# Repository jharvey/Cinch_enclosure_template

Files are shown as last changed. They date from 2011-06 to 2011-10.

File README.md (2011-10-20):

### EMS controller

This is a Cinch ModeICE enclosure layout template. The intent is that this will function as a starting point containing the critical items of an engine management system, such that one can insert thier CPU of choice and much of the hardware layout ect has already been drafted.

It includes the enclosure with thermal bars, left and right spring brackets, and a couple of potentail connectors that includes lots of great layout details. Included are the OEM Cinch 60 pin harness connector, and a Molex 112 pin connector.

The 3D of the enclosure was provided by Modice and is not the offical copy, it is current at the time this was created, but it could get out of date. The 3D assembly models are were often created in solidworks, and then imported to KICAD via TTConv0.2.

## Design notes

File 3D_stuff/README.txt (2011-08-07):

For the full 3Dstuff dir, that includes Solidworks files, DXF files, and other such CAD, see this github copy

commit  c3bbe558f4f0b5641e87
tree    d143f92a7165eae8b8e6
parent  c4be0f84e3a4aa974f0e

For zipped copy of 3DSTUFF folder see this copy in git hub

commit  38f78dee2a54a77aab6d
tree    d58a619a9214489eaf4b
parent  c3bbe558f4f0b5641e87

3DSTUFF folder was removed for space purposes.

I have included two step files of the assembly, these contain the outside faces, and the larger one include a rough idea of what's inside the enclosure.

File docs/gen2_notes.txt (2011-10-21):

Notes for gen2

Different harness connector, one that goes straight to the PCB, and has power devices dumping heat out the back. Perhaps with 2 connectors such that analog stuff can appraoch the processor in a start config. 

install the SP720 and SP723 earlier on, such that they are included.

Modularize parts if it like th injectocts, such that sub boards can be bulk processed. For example, 4 low side drive, or the WO2 circuit.

change AN/DIGI protect parts to smaller SMT, such that they can be packed tighter together.

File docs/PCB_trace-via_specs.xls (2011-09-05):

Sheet: .5oz PCB_trace-via_specs
Key notes from the below (summary .5oz copper)
A min trace width of 10 mills, is good for 8/8 PCB houses and can handle .537 external amps and .268 internal amps
For 1 amp and .5 oz copper, use a trace width wider than 23.7 mil external, and 61.5 mills internal. Min via drill of 20 mil.
For 5 amp and .5 oz copper, use a trace width wider than 218 mil external, and 566 mills internal. Min via drill of 45 mil.
For 10 amp and .5 oz copper, use a trace width wider than 566 mil external, and 1470 mills internal. Min via drill of 123 mil.
Per online calculator found here http://circuitcalculator.com/wordpress/2006/01/31/pcb-trace-width-calculator
min via's from http://batchpcb.com/index.php/Faq via calcs from http://circuitcalculator.com/wordpress/2006/03/12/pcb-via-calculator/
10 mill wide trace (min recommended for an 8/8 PCB house) |  |  |  | 13 mil min drill diameter
current .537 A |  | current .268 A |  | 15 | mil finished hole dia
.5 oz/ft^2 |  | .5 oz/ft^2 |  | 1 | mil plating thickness
temp rise 10 c |  | temp rise 10 c |  | 60 | mil via length
ambient 25 c |  | ambient 25 c
1 inch long |  | 1 inch long |  | 4 | amps applied
 |  |  |  | 1.9e-06 | Ohm-cm plating resistivity
--- for and external trace--- |  | --- for an internal trace---
internal trace |  | internal trace |  | 0.000893 | Ohms
26.1 | mill | 10 | mill | 0.0357 | Volts dropped
0.0387 | ohm | 0.1010 | ohm | 0.0143 | Watts dissipated
0.0208 | V drop | 0.0270 | V drop | 2.26 | Amps estimated ampacity
0.0112 | Watts | 0.00724 | Watts
external trace |  | external trace
10 | mill | 3.85 | mill
0.1010 | ohm | 0.262 | ohm
0.0540 | V drop | 0.070 | V drop
0.0290 | Watts | 0.019 | Watts
Trace width |  |  | via calcs
current 1 A |  |  | 15 | mil finished hole dia
.5 oz/ft^2 |  |  | 1 | mil plating thickness
temp rise 10 c |  |  | 60 | mil via length
ambient 25 c |  |  | 13 | drill dia
1 inch long |  |  | 1 | amps applied
 |  |  | 1.9e-06 | Ohm-cm plating resistivity
internal trace
61.5 | mill |  | 0.000893 | Ohms
0.0164 | ohm |  | 0.0357 | Volts dropped
0.0164 | V drop |  | 0.0143 | Watts dissipated
0.0164 | Watts |  | 2.26 | Amps estimated ampacity
external trace
23.7 | mill
0.0427 | ohm
0.0427 | V drop
0.0427 | Watts
Trace width |  |  | via calcs
current 5 A |  |  | 47 | mil finished hole dia
.5 oz/ft^2 |  |  | 1 | mil plating thickness
temp rise 10 c |  |  | 60 | mil via length
ambient 25 c |  |  | 45 | drill dia
1 inch long |  |  | 1 | amps applied
 |  |  | 1.9e-06 | Ohm-cm plating resistivity
internal trace
566 | mill |  | 0.000298 | Ohms
0.0018 | ohm |  | 0.00149 | Volts dropped
0.0089 | V drop |  | 0.00744 | Watts dissipated
0.0445 | Watts |  | 5.02 | Amps estimated ampacity
external trace
218 | mill
0.0046 | ohm
0.0232 | V drop
0.1160 | Watts
Trace width |  |  | via calcs
current 10 A |  |  | 125 | mil finished hole dia
.5 oz/ft^2 |  |  | 1 | mil plating thickness
temp rise 10 c |  |  | 60 | mil via length
ambient 25 c |  |  | 123 | drill dia
1 inch long |  |  | 10 | amps applied
 |  |  | 1.9e-06 | Ohm-cm plating resistivity
internal trace
14700 | mill |  | 0.000113 | Ohms
0.0007 | ohm |  | 0.00113 | Volts dropped
0.0069 | V drop |  | 0.0113 | Watts dissipated
0.0685 | Watts |  | 10.1 | Amps estimated ampacity
external trace
566 | mill
0.0018 | ohm
0.0178 | V drop
0.1780 | Watts

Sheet: 1oz PCB_trace-via_specs
Key notes from the below (summary 1oz copper)
A min trace width of 10 mills, is good for 8/8 PCB houses and can handle .886 external amps and .444 internal amps
For 1 amp and 1 oz copper, use a trace width wider than 11.8 mil external, and 30.8 mills internal. Min via drill of 20 mil.
For 5 amp and 1 oz copper, use a trace width wider than 109 mil external, and 283 mills internal. Min via drill of 45 mil.
For 10 amp and 1 oz copper, use a trace width wider than 283 mil external, and 737 mills internal. Min via drill of 123 mil.
Per online calculator found here http://circuitcalculator.com/wordpress/2006/01/31/pcb-trace-width-calculator
min via's from http://batchpcb.com/index.php/Faq via calcs from http://circuitcalculator.com/wordpress/2006/03/12/pcb-via-calculator/
9 mill wide trace (KICAD help file class 4 IPC class?) |  |  |  | 13 mil min drill diameter
current .8201 A |  | current .4101 A |  | 15 | mil finished hole dia
1 oz/ft^2 |  | 1 oz/ft^2 |  | 1 | mil plating thickness
temp rise 10 c |  | temp rise 10 c |  | 60 | mil via length
ambient 25 c |  | ambient 25 c
1 inch long |  | 1 inch long |  | 4 | amps applied
 |  |  |  | 1.9e-06 | Ohm-cm plating resistivity
--- for and external trace--- |  | --- for an internal trace---
internal trace |  | internal trace |  | 0.000893 | Ohms
23.4 | mill | 9 | mill | 0.0357 | Volts dropped
0.0216 | ohm | 0.0561 | ohm | 0.0143 | Watts dissipated
0.0177 | V drop | 0.0230 | V drop | 2.26 | Amps estimated ampacity
0.0145 | Watts | 0.0094 | Watts
external trace |  | external trace
9 | mill | 3.46 | mill
0.0561 | ohm | 0.146 | ohm
0.0460 | V drop | 0.060 | V drop
0.0377 | Watts | 0.025 | Watts
10 mill wide trace (min recommended for an 8/8 PCB house) |  |  |  | 20 mil min drill diameter
current .886 A |  | current .444 A |  | 22 | mil finished hole dia
1 oz/ft^2 |  | 1 oz/ft^2 |  | 1 | mil plating thickness
temp rise 10 c |  | temp rise 10 c |  | 60 | mil via length
ambient 25 c |  | ambient 25 c
1 inch long |  | 1 inch long |  | 2.94 | amps applied
 |  |  |  | 1.9e-06 | Ohm-cm plating resistivity
--- for and external trace--- |  | --- for an internal trace---
internal trace |  | internal trace |  | 0.000621 | Ohms
26 | mill | 10 | mill | 0.00183 | Volts dropped
0.0194 | ohm | 0.0503 | ohm | 0.00537 | Watts dissipated
0.0172 | V drop | 0.0223 | V drop | 2.94 | Amps estimated ampacity
0.0152 | Watts | 0.0099 | Watts
external trace |  | external trace
10 | mill | 3.86 | mill
0.0504 | ohm | 0.131 | ohm
0.0447 | V drop | 0.058 | V drop
0.0396 | Watts | 0.026 | Watts
Trace width |  |  | via calcs
current 1 A |  |  | 15 | mil finished hole dia
1 oz/ft^2 |  |  | 1 | mil plating thickness
temp rise 10 c |  |  | 60 | mil via length
ambient 25 c |  |  | 13 | drill dia
1 inch long |  |  | 1 | amps applied
 |  |  | 1.9e-06 | Ohm-cm plating resistivity
internal trace
30.8 | mill |  | 0.000893 | Ohms
0.0164 | ohm |  | 0.0357 | Volts dropped
0.0164 | V drop |  | 0.0143 | Watts dissipated
0.0164 | Watts |  | 2.26 | Amps estimated ampacity
external trace
11.8 | mill
0.0427 | ohm
0.0427 | V drop
0.0427 | Watts
Trace width |  |  | via calcs
current 5 A |  |  | 47 | mil finished hole dia
1 oz/ft^2 |  |  | 1 | mil plating thickness
temp rise 10 c |  |  | 60 | mil via length
ambient 25 c |  |  | 45 | drill dia
1 inch long |  |  | 1 | amps applied
 |  |  | 1.9e-06 | Ohm-cm plating resistivity
internal trace
283 | mill |  | 0.000298 | Ohms
0.0018 | ohm |  | 0.00149 | Volts dropped
0.0089 | V drop |  | 0.00744 | Watts dissipated
0.0445 | Watts |  | 5.02 | Amps estimated ampacity
external trace
109 | mill
0.0046 | ohm
0.0232 | V drop
0.1160 | Watts
Trace width |  |  | via calcs
current 10 A |  |  | 125 | mil finished hole dia
1 oz/ft^2 |  |  | 1 | mil plating thickness
temp rise 10 c |  |  | 60 | mil via length
ambient 25 c |  |  | 123 | drill dia
1 inch long |  |  | 10 | amps applied
 |  |  | 1.9e-06 | Ohm-cm plating resistivity
internal trace
737 | mill |  | 0.000113 | Ohms
0.0007 | ohm |  | 0.00113 | Volts dropped
0.0069 | V drop |  | 0.0113 | Watts dissipated
0.0685 | Watts |  | 10.1 | Amps estimated ampacity
external trace
283 | mill
0.0018 | ohm
0.0178 | V drop
0.1780 | Watts

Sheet: 2oz PCB_trace-via_specs
Key notes from the below (summary 2oz copper)
A min trace width of 10 mills, is good for 8/8 PCB houses and can handle 1.465 external amps and .734 internal amps
For 1 amp and 2 oz copper, use a trace width wider than 5.91 mil external, and 15.4 mills internal. Min via drill of 20 mil.
For 5 amp and 2 oz copper, use a trace width wider than 54.4 mil external, and 142 mills internal. Min via drill of 45 mil.
For 10 amp and 2 oz copper, use a trace width wider than 142 mil external, and 368 mills internal. Min via drill of 123 mil.
Per online calculator found here http://circuitcalculator.com/wordpress/2006/01/31/pcb-trace-width-calculator
min via's from http://batchpcb.com/index.php/Faq via calcs from http://circuitcalculator.com/wordpress/2006/03/12/pcb-via-calculator/
10 mill wide trace (min recommended for an 8/8 PCB house) |  |  |  | 20 mil min drill diameter
current 1.465 A |  | current .734 A |  | 22 | mil finished hole dia
2 oz/ft^2 |  | 2 oz/ft^2 |  | 1 | mil plating thickness
temp rise 10 c |  | temp rise 10 c |  | 60 | mil via length
ambient 25 c |  | ambient 25 c
1 inch long |  | 1 inch long |  | 2.94 | amps applied
 |  |  |  | 1.9e-06 | Ohm-cm plating resistivity
--- for and external trace--- |  | --- for an internal trace---
internal trace |  | internal trace |  | 0.000621 | Ohms
26 | mill | 10 | mill | 0.00183 | Volts dropped
0.0097 | ohm | 0.0251 | ohm | 0.00537 | Watts dissipated
0.0421 | V drop | 0.0184 | V drop | 2.94 | Amps estimated ampacity
0.0208 | Watts | 0.0135 | Watts
external trace |  | external trace
10 | mill | 3.86 | mill
0.0252 | ohm | 0.065 | ohm
0.0369 | V drop | 0.048 | V drop
0.0541 | Watts | 0.035 | Watts
Trace width |  |  | via calcs
current 1 A |  |  | 15 | mil finished hole dia
2 oz/ft^2 |  |  | 1 | mil plating thickness
temp rise 10 c |  |  | 60 | mil via length
ambient 25 c |  |  | 13 | drill dia
1 inch long |  |  | 1 | amps applied
 |  |  | 1.9e-06 | Ohm-cm plating resistivity
internal trace
15.4 | mill |  | 0.000893 | Ohms
0.0164 | ohm |  | 0.0357 | Volts dropped
0.0164 | V drop |  | 0.0143 | Watts dissipated
0.0164 | Watts |  | 2.26 | Amps estimated ampacity
external trace
5.91 | mill
0.0427 | ohm
0.0427 | V drop
0.0427 | Watts
Trace width |  |  | via calcs
current 5 A |  |  | 47 | mil finished hole dia
2 oz/ft^2 |  |  | 1 | mil plating thickness
temp rise 10 c |  |  | 60 | mil via length
ambient 25 c |  |  | 45 | drill dia
1 inch long |  |  | 1 | amps applied
 |  |  | 1.9e-06 | Ohm-cm plating resistivity
internal trace
142 | mill |  | 0.000298 | Ohms
0.0018 | ohm |  | 0.00149 | Volts dropped
0.0089 | V drop |  | 0.00744 | Watts dissipated
0.0445 | Watts |  | 5.02 | Amps estimated ampacity
external trace
54.4 | mill
0.0046 | ohm
0.0232 | V drop
0.1160 | Watts
Trace width |  |  | via calcs
current 10 A |  |  | 125 | mil finished hole dia
2 oz/ft^2 |  |  | 1 | mil plating thickness
temp rise 10 c |  |  | 60 | mil via length
ambient 25 c |  |  | 123 | drill dia
1 inch long |  |  | 10 | amps applied
 |  |  | 1.9e-06 | Ohm-cm plating resistivity
internal trace
368 | mill |  | 0.000113 | Ohms
0.0007 | ohm |  | 0.00113 | Volts dropped
0.0069 | V drop |  | 0.0113 | Watts dissipated
0.0685 | Watts |  | 10.1 | Amps estimated ampacity
external trace
142 | mill
0.0018 | ohm
0.0178 | V drop
0.1780 | Watts

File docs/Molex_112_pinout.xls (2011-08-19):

Connector | pin# |  | pin size | Signal | Alt signal | notes
1 - Center | 1 | A | small | Ign 1
1 - Center | 1 | B | small | optout 1
1 - Center | 1 | C | small | 5V sensor supply
1 - Center | 1 | D | small | Crank+
1 - Center | 1 | E | small | O2 VM 1
1 - Center | 1 | F | small | CAN1 L
1 - Center | 1 | G | small | GND sense
1 - Center | 1 | H | small | optout 5
1 - Center | 1 | J | small | 5V general supply |  | do we need this?
1 - Center | 1 | K | small | Stepper 1-1
1 - Center | 1 | L | large | GND 1-1
1 - Center | 1 | M | large | Inj 1
1 - Center | 2 | A | small | Ign 2
1 - Center | 2 | B | small | optout 2
1 - Center | 2 | C | small | MAP
1 - Center | 2 | D | small | Crank-
1 - Center | 2 | E | small | O2 UM1
1 - Center | 2 | F | small | CAN1 H
1 - Center | 2 | G | small | Analog in 2
1 - Center | 2 | H | small | optout 6
1 - Center | 2 | J | small | Knock 1 +
1 - Center | 2 | K | small | Stepper 1-2
1 - Center | 2 | L | large | GND 1-2
1 - Center | 2 | M | large | Inj 2
1 - Center | 3 | A | small | Ign 3
1 - Center | 3 | B | small | optout 3
1 - Center | 3 | C | small | TPS
1 - Center | 3 | D | small | Cam+
1 - Center | 3 | E | small | O2 IP 1
1 - Center | 3 | F | small | 232 RX
1 - Center | 3 | G | small | Analog in 1
1 - Center | 3 | H | small | Analog in 4
1 - Center | 3 | J | small | Knock 1 -
1 - Center | 3 | K | small | Stepper 1-3
1 - Center | 3 | L | large | Fuel pump
1 - Center | 3 | M | large | Inj 3
1 - Center | 4 | A | small | Ign 4
1 - Center | 4 | B | small | opt out 4
1 - Center | 4 | C | small | Coolant Temp
1 - Center | 4 | D | small | Cam-
1 - Center | 4 | E | small | O2 1 - IA 1
1 - Center | 4 | F | small | 232 TX
1 - Center | 4 | G | small | Air Temp
1 - Center | 4 | H | small | O2 Heater 1
1 - Center | 4 | J | small | Analog in 3
1 - Center | 4 | K | small | Stepper 1-4
1 - Center | 4 | L | large | 12V 1
1 - Center | 4 | M | large | Inj 4
2 - Left | 1 | A | small | Ign 5
2 - Left | 1 | B | small | Analog in 5
2 - Left | 1 | C | small | O2 VM2
2 - Left | 1 | D | small | wheel 1 +
2 - Left | 1 | E | small | wheel 1 -
2 - Left | 1 | F | small | Stepper 2 - 1
2 - Left | 1 | G | large | GND 2-1
2 - Left | 1 | H | large | Inj 5
2 - Left | 2 | A | small | Ign 6
2 - Left | 2 | B | small | Analog in 6
2 - Left | 2 | C | small | O2 UM2
2 - Left | 2 | D | small | wheel 2 +
2 - Left | 2 | E | small | wheel 2 -
2 - Left | 2 | F | small | Stepper 2 - 2
2 - Left | 2 | G | large | GND 2-1
2 - Left | 2 | H | large | Inj 6
2 - Left | 3 | A | small | Ign 7
2 - Left | 3 | B | small | Analog in 7
2 - Left | 3 | C | small | O2 IP2
2 - Left | 3 | D | small | wheel 3 +
2 - Left | 3 | E | small | wheel 3 -
2 - Left | 3 | F | small | Stepper 2 - 3
2 - Left | 3 | G | large | GND2-2
2 - Left | 3 | H | large | Inj 7
2 - Left | 4 | A | small | Ign 8
2 - Left | 4 | B | small | O2 Heater2
2 - Left | 4 | C | small | O2 2 - IA
2 - Left | 4 | D | small | wheel 4 +
2 - Left | 4 | E | small | wheel 4 -
2 - Left | 4 | F | small | Stepper 2- 4
2 - Left | 4 | G | large | 12V 2
2 - Left | 4 | H | large | Inj 8
3 - Right | 1 | A | small | Ign 9
3 - Right | 1 | B | small | optout 7 | inj 13
3 - Right | 1 | C | small | optout 11 | inj 17
3 - Right | 1 | D | small | optout 15 | inj 21
3 - Right | 1 | E | small | Analog in 8
3 - Right | 1 | F | small | analog in 9
3 - Right | 1 | G | large | GND 3-1
3 - Right | 1 | H | large | Inj 9
3 - Right | 2 | A | small | Ign 10
3 - Right | 2 | B | small | optout 8 | inj 14
3 - Right | 2 | C | small | optout 12 | inj 18
3 - Right | 2 | D | small | optout 16 | inj 22
3 - Right | 2 | E | small | analog in 10
3 - Right | 2 | F | small | analog in 11
3 - Right | 2 | G | large | GND 3-2
3 - Right | 2 | H | large | Inj 10
3 - Right | 3 | A | small | Ign 11
3 - Right | 3 | B | small | optout 9 | inj 15
3 - Right | 3 | C | small | optout 13 | inj 19
3 - Right | 3 | D | small | optout 17 | inj 23
3 - Right | 3 | E | small | 232 TX2 |  | do we need this?
3 - Right | 3 | F | small | CAN2 L |  | do we need this?
3 - Right | 3 | G | large | GND3-3
3 - Right | 3 | H | large | Inj 11
3 - Right | 4 | A | small | Ign 12
3 - Right | 4 | B | small | optout 10 | inj 16
3 - Right | 4 | C | small | optout 14 | inj 20
3 - Right | 4 | D | small | optout 18 | inj 24
3 - Right | 4 | E | small | 232 RX2 |  | do we need this?
3 - Right | 4 | F | small | CAN2 H |  | do we need this?
3 - Right | 4 | G | large | GND3-4
3 - Right | 4 | H | large | Inj 12

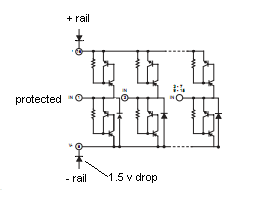
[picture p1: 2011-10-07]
pictures/ESD_theory.PNG

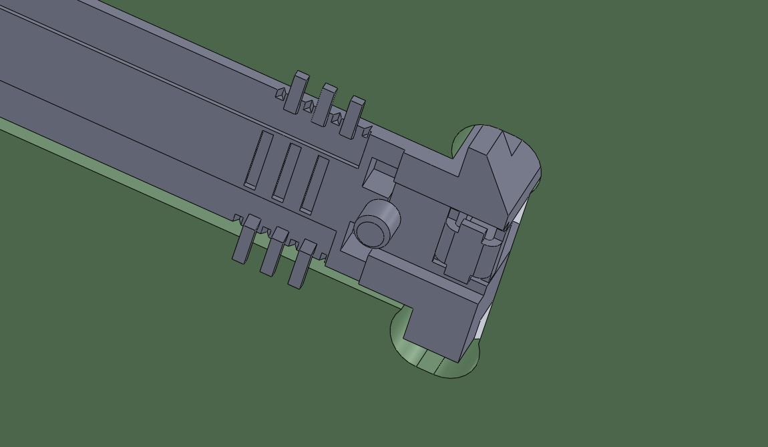
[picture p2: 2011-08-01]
pictures/som_bottom_view.jpg

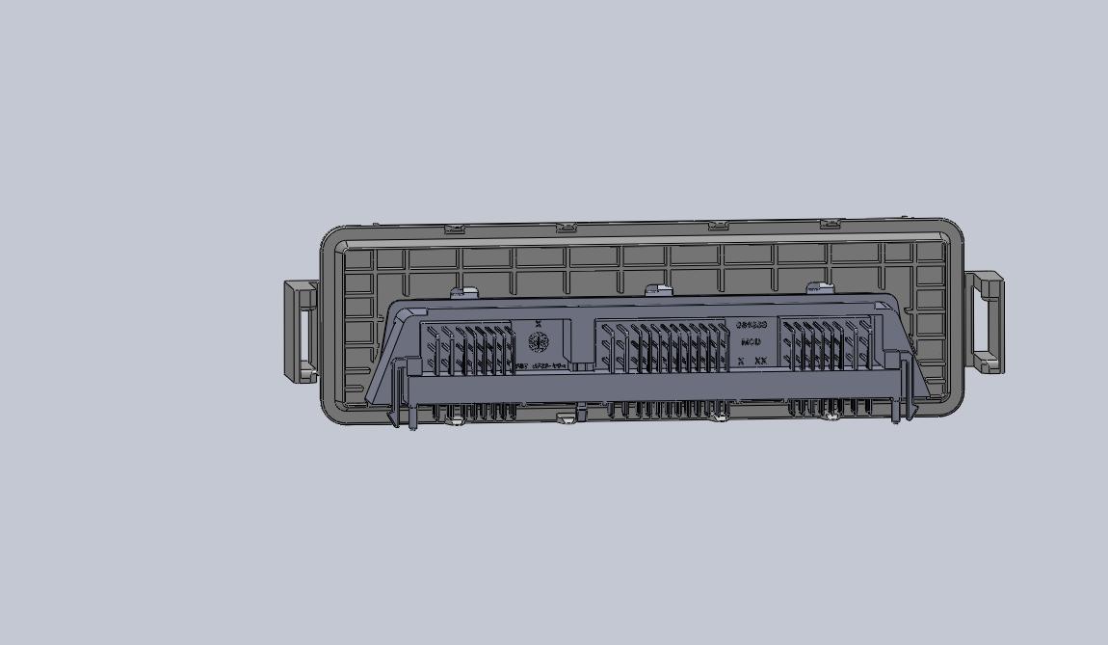
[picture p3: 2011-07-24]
pictures/modeice_case_iso3.jpg

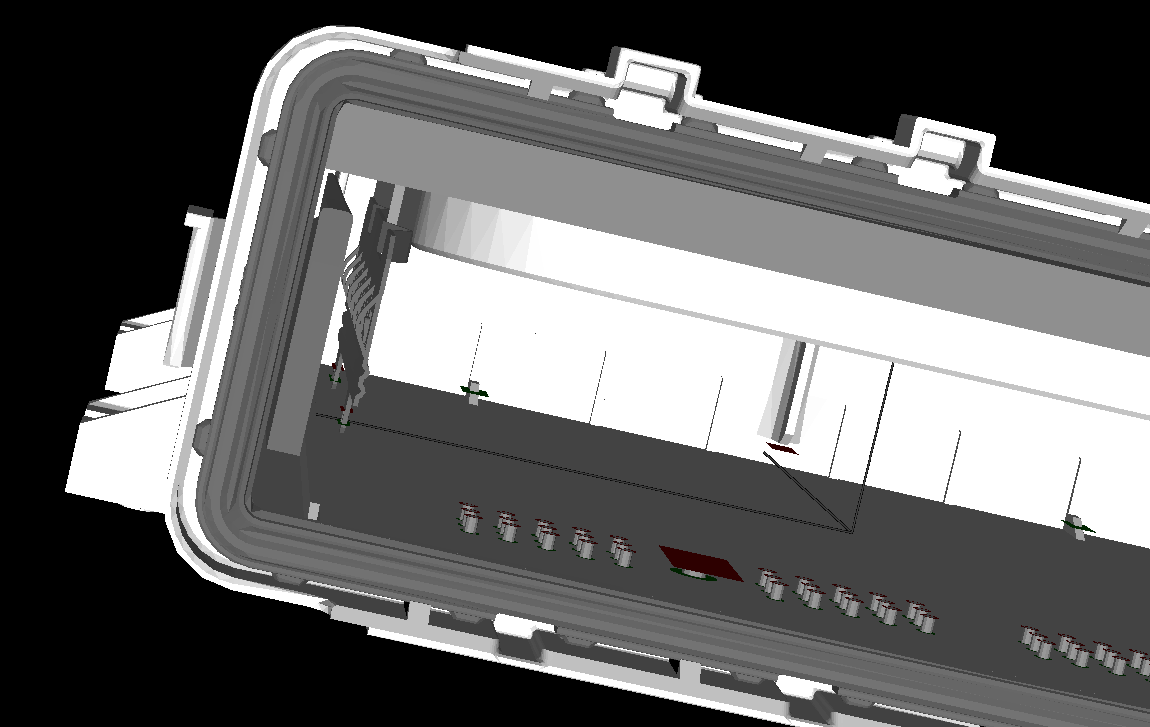
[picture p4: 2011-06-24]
pictures/cinch_spring_clips1.png

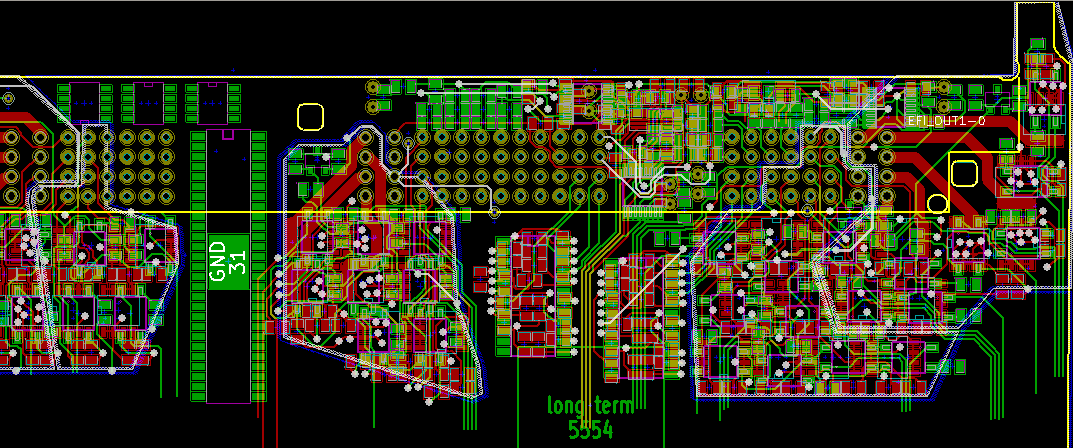
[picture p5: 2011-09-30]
pictures/layout_top_view_09-26-11.PNG

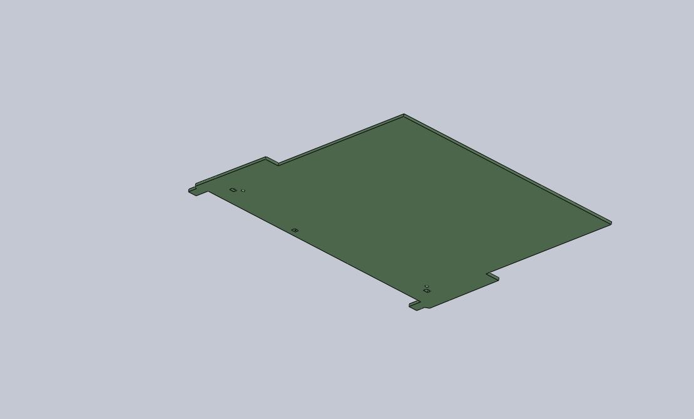
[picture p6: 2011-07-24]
pictures/pcb_outline.jpg

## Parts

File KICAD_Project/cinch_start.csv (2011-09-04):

ref | value | footprint | Field1 | Field2 | Field3 | Field4 | Field5 | Field6 | Field7 | Field8
C401 | 100nf | SM0805-C1 | avx | 08051C104KAT2A | newark | 96M1354 |  |  | 100V | 10% | ceramic | other | more | stuff
C402 | 100nf | SM0805-C1 | avx | 08051C104KAT2A | newark | 96M1354 |  |  | 100V | 10% | ceramic | other | more | stuff
C403 | 100nf | SM0805-C1 | avx | 08051C104KAT2A | newark | 96M1354 |  |  | 100V | 10% | ceramic | other | more | stuff
C404 | 100nf | SM0805-C1 | avx | 08051C104KAT2A | newark | 96M1354 |  |  | 100V | 10% | ceramic | other | more | stuff
C405 | 100nf | SM0805-C1 | avx | 08051C104KAT2A | newark | 96M1354 |  |  | 100V | 10% | ceramic | other | more | stuff
C406 | 100nf | SM0805-C1 | avx | 08051C104KAT2A | newark | 96M1354 |  |  | 100V | 10% | ceramic | other | more | stuff
C407 | 100nf | SM0805-C1 | avx | 08051C104KAT2A | newark | 96M1354 |  |  | 100V | 10% | ceramic | other | more | stuff
C408 | 100nf | SM0805-C1 | avx | 08051C104KAT2A | newark | 96M1354 |  |  | 100V | 10% | ceramic | other | more | stuff
C409 | 100nf | SM0805-C1 | avx | 08051C104KAT2A | newark | 96M1354 |  |  | 100V | 10% | ceramic | other | more | stuff
C410 | 100nf | SM0805-C1 | avx | 08051C104KAT2A | newark | 96M1354 |  |  | 100V | 10% | ceramic | other | more | stuff
C411 | 100nf | SM0805-C1 | avx | 08051C104KAT2A | newark | 96M1354 |  |  | 100V | 10% | ceramic | other | more | stuff
C412 | 100nf | SM0805-C1 | avx | 08051C104KAT2A | newark | 96M1354 |  |  | 100V | 10% | ceramic | other | more | stuff
C413 | 100nf | SM0805-C1 | avx | 08051C104KAT2A | newark | 96M1354 |  |  | 100V | 10% | ceramic | other | more | stuff
C414 | 100nf | SM0805-C1 | avx | 08051C104KAT2A | newark | 96M1354 |  |  | 100V | 10% | ceramic | other | more | stuff
C415 | 100nf | SM0805-C1 | avx | 08051C104KAT2A | newark | 96M1354 |  |  | 100V | 10% | ceramic | other | more | stuff
C416 | 100nf | SM0805-C1 | avx | 08051C104KAT2A | newark | 96M1354 |  |  | 100V | 10% | ceramic | other | more | stuff
C417 | 100nf | SM0805-C1 | avx | 08051C104KAT2A | newark | 96M1354 |  |  | 100V | 10% | ceramic | other | more | stuff
C418 | 100nf | SM0805-C1 | avx | 08051C104KAT2A | newark | 96M1354 |  |  | 100V | 10% | ceramic | other | more | stuff
C419 | 100nf | SM0805-C1 | avx | 08051C104KAT2A | newark | 96M1354 |  |  | 100V | 10% | ceramic | other | more | stuff
C420 | 100nf | SM0805-C1 | avx | 08051C104KAT2A | newark | 96M1354 |  |  | 100V | 10% | ceramic | other | more | stuff
C421 | 100nf | SM0805-C1 | avx | 08051C104KAT2A | newark | 96M1354 |  |  | 100V | 10% | ceramic | other | more | stuff
C422 | 100nf | SM0805-C1 | avx | 08051C104KAT2A | newark | 96M1354 |  |  | 100V | 10% | ceramic | other | more | stuff
C423 | 100nf | SM0805-C1 | avx | 08051C104KAT2A | newark | 96M1354 |  |  | 100V | 10% | ceramic | other | more | stuff
C424 | 100nf | SM0805-C1 | avx | 08051C104KAT2A | newark | 96M1354 |  |  | 100V | 10% | ceramic | other | more | stuff
C425 | 100nf | SM0805-C1 | avx | 08051C104KAT2A | newark | 96M1354 |  |  | 100V | 10% | ceramic | other | more | stuff
C426 | 100nf | SM0805-C1 | avx | 08051C104KAT2A | newark | 96M1354 |  |  | 100V | 10% | ceramic | other | more | stuff
C427 | 100nf | SM0805-C1 | avx | 08051C104KAT2A | newark | 96M1354 |  |  | 100V | 10% | ceramic | other | more | stuff
C428 | 100nf | SM0805-C1 | avx | 08051C104KAT2A | newark | 96M1354 |  |  | 100V | 10% | ceramic | other | more | stuff
C501 | 1uF | SM0805 | avx | 08051C103JAT2A | newark | 96M1352
C502 | 1uF | SM0805 | avx | 08051C103JAT2A | newark | 96M1352
C503 | 1uF | SM0805 | avx | 08051C103JAT2A | newark | 96M1352
C504 | 1uF | SM0805 | avx | 08051C103JAT2A | newark | 96M1352
C505 | 1uF | SM0805 | avx | 08051C103JAT2A | newark | 96M1352
C506 | 1uF | SM0805 | avx | 08051C103JAT2A | newark | 96M1352
C507 | 1uF | SM0805 | avx | 08051C103JAT2A | newark | 96M1352
C508 | 1uF | SM0805 | avx | 08051C103JAT2A | newark | 96M1352
C509 | 1uF | SM0805 | avx | 08051C103JAT2A | newark | 96M1352
C510 | 1uF | SM0805 | avx | 08051C103JAT2A | newark | 96M1352
C511 | 1uF | SM0805 | avx | 08051C103JAT2A | newark | 96M1352
C512 | 1uF | SM0805 | avx | 08051C103JAT2A | newark | 96M1352
C513 | 1uF | SM0805 | avx | 08051C103JAT2A | newark | 96M1352
C514 | 1uF | SM0805 | avx | 08051C103JAT2A | newark | 96M1352
C515 | 1uF | SM0805 | avx | 08051C103JAT2A | newark | 96M1352
C516 | 1uF | SM0805 | avx | 08051C103JAT2A | newark | 96M1352
C517 | 1uF | SM0805 | avx | 08051C103JAT2A | newark | 96M1352
C518 | 1uF | SM0805 | avx | 08051C103JAT2A | newark | 96M1352
C601 | 0.1uF | SM0805-C1 | avx | 08051C104KAT2A | newark | 96M1354 |  |  | 100V | 10% | ceramic | other | more | stuff
C602 | 0.1uF | SM0805-C1 | avx | 08051C104KAT2A | newark | 96M1354 |  |  | 100V | 10% | ceramic | other | more | stuff
C603 | 10uF | SM0805-C1 | AVX | 08053C104KAT2A | newark | 96M1381 |  |  | 25V | 10% | multi layer ceramic | other | more | stuff
C604 | 10uF | SM0805-C1 | AVX | 08053C104KAT2A | newark | 96M1381 |  |  | 25V | 10% | multi layer ceramic | other | more | stuff
C605 | 1nF | SM0805-C1 | avx | 08055F102K4Z2A | newark | 26M5154 | - | - | - | - | 10 | V | 10 | % | multilayer ceramic | other | more | stuff
C606 | 1nF | SM0805-C1 | avx | 08055F102K4Z2A | newark | 26M5154 | - | - | - | - | 50 | V | 10 | % | ceramic | other | more | stuff
C607 | 1nF | SM0805-C1 | avx | 08055F102K4Z2A | newark | 26M5154 | - | - | - | - | 10 | V | 10 | % | multilayer ceramic | other | more | stuff
C608 | 1nF | SM0805-C1 | avx | 08055F102K4Z2A | newark | 26M5154 | - | - | - | - | 50 | V | 10 | % | ceramic | other | more | stuff
C609 | 0.1uF | SM0805-C1 | avx | 08051C104KAT2A | newark | 96M1354 |  |  | 100V | 10% | ceramic | other | more | stuff
C610 | 0.1uF | SM0805-C1 | avx | 08051C104KAT2A | newark | 96M1354 |  |  | 100V | 10% | ceramic | other | more | stuff
C611 | 10uF | SM0805-C1 | AVX | 08053C104KAT2A | newark | 96M1381 |  |  | 25V | 10% | multi layer ceramic | other | more | stuff
C612 | 10uF | SM0805-C1 | AVX | 08053C104KAT2A | newark | 96M1381 |  |  | 25V | 10% | multi layer ceramic | other | more | stuff
C613 | 1nF | SM0805-C1 | avx | 08055F102K4Z2A | newark | 26M5154 | - | - | - | - | 10 | V | 10 | % | multilayer ceramic | other | more | stuff
C614 | 1nF | SM0805-C1 | avx | 08055F102K4Z2A | newark | 26M5154 | - | - | - | - | 50 | V | 10 | % | ceramic | other | more | stuff
C615 | 1nF | SM0805-C1 | avx | 08055F102K4Z2A | newark | 26M5154 | - | - | - | - | 10 | V | 10 | % | multilayer ceramic | other | more | stuff
C616 | 1nF | SM0805-C1 | avx | 08055F102K4Z2A | newark | 26M5154 | - | - | - | - | 50 | V | 10 | % | ceramic | other | more | stuff
C701 | 10uF | SM0805-C1 | AVX | 08053C104KAT2A | newark | 96M1381 |  |  | 25V | 10% | multi layer ceramic | other | more | stuff
C702 | 10uF | SM0805-C1 | AVX | 08053C104KAT2A | newark | 96M1381 |  |  | 25V | 10% | multi layer ceramic | other | more | stuff
C703 | 0.1uF | SM0805-C1 | avx | 08051C104KAT2A | newark | 96M1354 |  |  | 100V | 10% | ceramic | other | more | stuff
C704 | 0.1uF | SM0805-C1 | avx | 08051C104KAT2A | newark | 96M1354 |  |  | 100V | 10% | ceramic | other | more | stuff
C705 | 100nF | SM0805-C1 | avx | 08051C104KAT2A | newark | 96M1354 |  |  | 100V | 10% | ceramic | other | more | stuff
C706 | 10uF | SM0805-C1 | AVX | 08053C104KAT2A | newark | 96M1381 |  |  | 25V | 10% | multi layer ceramic | other | more | stuff
C707 | 0.1uF | SM0805-C1 | avx | 08051C104KAT2A | newark | 96M1354 |  |  | 100V | 10% | ceramic | other | more | stuff
C708 | 100uF | SM0805-C1 | avx | 08051C104KAT2A | newark | 96M1354 |  |  | 100V | 10% | ceramic | other | more | stuff
C709 | 100nF | SM0805-C1 | avx | 08051C104KAT2A | newark | 96M1354 |  |  | 100V | 10% | ceramic | other | more | stuff
C710 | 22uF | SM2512 | AVX | TAJC226M016RNJ | digikey | 478-3901-1-ND | 16v | 20% | tantalum | other | more | stuff
C711 | 22uF | SM2512 | AVX | TAJC226M016RNJ | digikey | 478-3901-1-ND | 16v | 20% | tantalum | other | more | stuff
C712 | 0.1uF | SM0805-C1 | avx | 08051C104KAT2A | newark | 96M1354 |  |  | 100V | 10% | ceramic | other | more | stuff
C713 | 0.1uF | SM0805-C1 | avx | 08051C104KAT2A | newark | 96M1354 |  |  | 100V | 10% | ceramic | other | more | stuff
C714 | 100uF | SM0805-C1 | avx | 08051C104KAT2A | newark | 96M1354 |  |  | 100V | 10% | ceramic | other | more | stuff
C715 | 100nF | SM0805-C1 | avx | 08051C104KAT2A | newark | 96M1354 |  |  | 100V | 10% | ceramic | other | more | stuff
C716 | 22uF | SM2512 | AVX | TAJC226M016RNJ | digikey | 478-3901-1-ND | 16v | 20% | tantalum | other | more | stuff
C717 | 0.1uF | SM0805-C1 | avx | 08051C104KAT2A | newark | 96M1354 |  |  | 100V | 10% | ceramic | other | more | stuff
C718 | 2200uF | C1V8 | United Chemi-Con | EKZE6R3ELL222MJ25S | digikey | 565-1634-ND | 6.3v | 20% | aluminum | other | more | stuff
C719 | 5.6nF | SM0805-C1 | ill cap | 226CKH050M | newark | 69K7919 | - | - | - | - | 50 | V | 20 | % | alum electro | other | more | stuff
C720 | 27pF | SM0805-C1 | avx | 08051A221JAT2A | newark | 96K4770 | - | - | - | - | 100 | V | 5 | % | ceramic | other | more | stuff
C721 | 330uF | SM0805-C1 | kemet | T495X337K010ATE035 | newark | 69K7939 | - | - | - | - | 25 | V | 20 | % | alum electro | other | more | stuff
C722 | 10uF | SM0805-C1 | AVX | 08053C104KAT2A | newark | 96M1381 |  |  | 25V | 10% | multi layer ceramic | other | more | stuff
C723 | 10nF | SM0805-C1 | ill cap | 106CKE200M | newark | 69K7896 |  |  | 200V | 10% | alum elec | other | more | stuff
C801 | 470uF | SM0805-C1 | ill cap | 106CKE200M | newark | 69K7896 | - | - | - | - | 200 | V | 20 | % | alum electro | other | more | stuff
C802 | 10uF | SM0805-C1 | AVX | 08053C104KAT2A | newark | 96M1381 |  |  | 25V | 10% | multi layer ceramic | other | more | stuff
C803 | 100nF | SM0805-C1 | avx | 08051C104KAT2A | newark | 96M1354 |  |  | 100V | 10% | ceramic | other | more | stuff
C804 | 470uF | SM0805-C1 | ill cap | 106CKE200M | newark | 69K7896 | - | - | - | - | 200 | V | 20 | % | alum electro | other | more | stuff
C805 | 100nF | SM0805-C1 | ill cap | 106CKE200M | newark | 69K7896 | - | - | - | - | 200 | V | 20 | % | alum electro | other | more | stuff
C901 | 22nF | SM0805-C1 | murata | GRM216R71H223KA01D | newark | 38K1698 | - | - | 50 | V | 10 | % | Ceramic | other | more | stuff
C902 | 10uF | SM0805-C1 | AVX | 08053C104KAT2A | newark | 96M1381 |  |  | 25V | 10% | multi layer ceramic | other | more | stuff
C903 | 100nF | SM0805-C1 | avx | 08051C104KAT2A | newark | 96M1354 |  |  | 100V | 10% | ceramic | other | more | stuff
C904 | 22nF | SM0805-C1 | murata | GRM216R71H223KA01D | newark | 38K1698 | - | - | 50 | V | 10 | % | Ceramic | other | more | stuff
C905 | 22nF | SM0805-C1 | murata | GRM216R71H223KA01D | newark | 38K1698 | - | - | 50 | V | 10 | % | Ceramic | other | more | stuff
C906 | 100nF | SM0805-C1 | avx | 08051C104KAT2A | newark | 96M1354 |  |  | 100V | 10% | ceramic | other | more | stuff
C907 | 100uF | SM0805-C1 | avx | 08051C104KAT2A | newark | 96M1354 |  |  | 100V | 10% | ceramic | other | more | stuff
C908 | 22nF | SM0805-C1 | murata | GRM216R71H223KA01D | newark | 38K1698 | - | - | 50 | V | 10 | % | Ceramic | other | more | stuff
C909 | 22nF | SM0805-C1 | murata | GRM216R71H223KA01D | newark | 38K1698 | - | - | 50 | V | 10 | % | Ceramic | other | more | stuff
C1001 | 10nF | SM0805-C1 | ill cap | 106CKE200M | newark | 69K7896 |  |  | 200V | 10% | alum elec | other | more | stuff
C1002 | 10nF | SM0805-C1 | ill cap | 106CKE200M | newark | 69K7896 |  |  | 200V | 10% | alum elec | other | more | stuff
C1003 | 10nF | SM0805-C1 | ill cap | 106CKE200M | newark | 69K7896 |  |  | 200V | 10% | alum elec | other | more | stuff
C1004 | 10nF | SM0805-C1 | ill cap | 106CKE200M | newark | 69K7896 |  |  | 200V | 10% | alum elec | other | more | stuff
C1005 | 10nF | SM0805-C1 | ill cap | 106CKE200M | newark | 69K7896 |  |  | 200V | 10% | alum elec | other | more | stuff
C1006 | 10nF | SM0805-C1 | ill cap | 106CKE200M | newark | 69K7896 |  |  | 200V | 10% | alum elec | other | more | stuff
C1007 | 10nF | SM0805-C1 | ill cap | 106CKE200M | newark | 69K7896 |  |  | 200V | 10% | alum elec | other | more | stuff
C1008 | 10nF | SM0805-C1 | ill cap | 106CKE200M | newark | 69K7896 |  |  | 200V | 10% | alum elec | other | more | stuff
C1009 | 10nF | SM0805-C1 | ill cap | 106CKE200M | newark | 69K7896 |  |  | 200V | 10% | alum elec | other | more | stuff
C1010 | 10nF | SM0805-C1 | ill cap | 106CKE200M | newark | 69K7896 |  |  | 200V | 10% | alum elec | other | more | stuff
C1011 | 10nF | SM0805-C1 | ill cap | 106CKE200M | newark | 69K7896 |  |  | 200V | 10% | alum elec | other | more | stuff
C1012 | 10nF | SM0805-C1 | ill cap | 106CKE200M | newark | 69K7896 |  |  | 200V | 10% | alum elec | other | more | stuff
C1013 | 10nF | SM0805-C1 | ill cap | 106CKE200M | newark | 69K7896 |  |  | 200V | 10% | alum elec | other | more | stuff
C1014 | 100nF | SM0805-C1 | avx | 08051C104KAT2A | newark | 96M1354 |  |  | 100V | 10% | ceramic | other | more | stuff
C1015 | 100nF | SM0805-C1 | avx | 08051C104KAT2A | newark | 96M1354 |  |  | 100V | 10% | ceramic | other | more | stuff
C1016 | 10nF | SM0805-C1 | ill cap | 106CKE200M | newark | 69K7896 |  |  | 200V | 10% | alum elec | other | more | stuff
C1017 | 10nF | SM0805-C1 | ill cap | 106CKE200M | newark | 69K7896 |  |  | 200V | 10% | alum elec | other | more | stuff
C1018 | 10nF | SM0805-C1 | ill cap | 106CKE200M | newark | 69K7896 |  |  | 200V | 10% | alum elec | other | more | stuff
C1019 | 10nF | SM0805-C1 | ill cap | 106CKE200M | newark | 69K7896 |  |  | 200V | 10% | alum elec | other | more | stuff
C1020 | 10nF | SM0805-C1 | ill cap | 106CKE200M | newark | 69K7896 |  |  | 200V | 10% | alum elec | other | more | stuff
C1021 | 10nF | SM0805-C1 | ill cap | 106CKE200M | newark | 69K7896 |  |  | 200V | 10% | alum elec | other | more | stuff
C1022 | 10nF | SM0805-C1 | ill cap | 106CKE200M | newark | 69K7896 |  |  | 200V | 10% | alum elec | other | more | stuff
C1023 | 10nF | SM0805-C1 | ill cap | 106CKE200M | newark | 69K7896 |  |  | 200V | 10% | alum elec | other | more | stuff
C1024 | 10nF | SM0805-C1 | ill cap | 106CKE200M | newark | 69K7896 |  |  | 200V | 10% | alum elec | other | more | stuff
C1101 | 100nF | SM0805-C1 | avx | 08051C104KAT2A | newark | 96M1354 |  |  | 100V | 10% | ceramic | other | more | stuff
C1102 | 10uF | SM0805-C1 | AVX | 08053C104KAT2A | newark | 96M1381 |  |  | 25V | 10% | multi layer ceramic | other | more | stuff
C1201 | 1nF | SM0805-C1 | avx | 08055F102K4Z2A | newark | 26M5154 | - | - | - | - | 50 | V | 10 | % | Ceramic | other | more | stuff
C1202 | 1nF | SM0805-C1 | avx | 08055F102K4Z2A | newark | 26M5154 | - | - | - | - | 50 | V | 10 | % | Ceramic | other | more | stuff
C1203 | 33nF | SM0805-C1 | yageo | CC0805KRX7R8BB333 | newark | 69C9599 |  |  | 25V | 10% | ceramic | other | more | stuff
C1204 | 33nF | SM0805-C1 | yageo | CC0805KRX7R8BB333 | newark | 69C9599 |  |  | 25V | 10% | ceramic | other | more | stuff
C1205 | 100nF | SM0805-C1 | avx | 08051C104KAT2A | newark | 96M1354 |  |  | 100V | 10% | ceramic | other | more | stuff
C1206 | 100nF | SM0805-C1 | avx | 08051C104KAT2A | newark | 96M1354 |  |  | 100V | 10% | ceramic | other | more | stuff
C1207 | 2.2nF | SM0805-C1 | avx | 08051A221JAT2A | newark | 96K4770 | - | - | - | - | 100 | V | 5 | % | Ceramic | other | more | stuff
C1208 | 2.2nF | SM0805-C1 | avx | 08051A221JAT2A | newark | 96K4770 | - | - | - | - | 100 | V | 5 | % | Ceramic | other | more | stuff
C1209 | 33nF | SM0805-C1 | yageo | CC0805KRX7R8BB333 | newark | 69C9599 |  |  | 25V | 10% | ceramic | other | more | stuff
C1210 | 33nF | SM0805-C1 | yageo | CC0805KRX7R8BB333 | newark | 69C9599 |  |  | 25V | 10% | ceramic | other | more | stuff
C1211 | 100nF | SM0805-C1 | avx | 08051C104KAT2A | newark | 96M1354 |  |  | 100V | 10% | ceramic | other | more | stuff
C1212 | 100nF | SM0805-C1 | avx | 08051C104KAT2A | newark | 96M1354 |  |  | 100V | 10% | ceramic | other | more | stuff
C1213 | 33nF | SM0805-C1 | yageo | CC0805KRX7R8BB333 | newark | 69C9599 |  |  | 25V | 10% | ceramic | other | more | stuff
C1214 | 33nF | SM0805-C1 | yageo | CC0805KRX7R8BB333 | newark | 69C9599 |  |  | 25V | 10% | ceramic | other | more | stuff
C1215 | 10nF | SM0805-C1 | ill cap | 106CKE200M | newark | 69K7896 |  |  | 200V | 10% | alum elec | other | more | stuff
C1216 | 10nF | SM0805-C1 | ill cap | 106CKE200M | newark | 69K7896 |  |  | 200V | 10% | alum elec | other | more | stuff
C1301 | 0.1uF | SM0805-C1 | avx | 08051C104KAT2A | newark | 96M1354 |  |  | 100V | 10% | ceramic | other | more | stuff
C1302 | 0.1uF | SM0805-C1 | avx | 08051C104KAT2A | newark | 96M1354 |  |  | 100V | 10% | ceramic | other | more | stuff
C1303 | 15nf | SM0805-C1 | avx | 08055C102KAT2A | digi | 478-1371-6-ND | 50 | V | 10 | % | Ceramic | other | more | stuff
C1304 | 15nf | SM0805-C1 | avx | 08055C102KAT2A | digi | 478-1371-6-ND | 50 | V | 10 | % | Ceramic | other | more | stuff
C1305 | 15nf | SM0805-C1 | avx | 08055C102KAT2A | digi | 478-1371-6-ND | 50 | V | 10 | % | Ceramic | other | more | stuff
C1306 | 0.1uF | SM0805-C1 | avx | 08051C104KAT2A | newark | 96M1354 |  |  | 100V | 10% | ceramic | other | more | stuff
C1307 | 0.1uF | SM0805-C1 | avx | 08051C104KAT2A | newark | 96M1354 |  |  | 100V | 10% | ceramic | other | more | stuff
C1308 | 0.1uF | SM0805-C1 | avx | 08051C104KAT2A | newark | 96M1354 |  |  | 100V | 10% | ceramic | other | more | stuff
C1309 | 1nF | SM0805-C1 | avx | 08055F102K4Z2A | newark | 26M5154 | - | - | 50 | v | 10 | % | ceramic | -
C1310 | 1nF | SM0805-C1 | avx | 08055F102K4Z2A | newark | 26M5154 | - | - | 50 | v | 10 | % | ceramic | -
C1311 | 1nF | SM0805-C1 | avx | 08055F102K4Z2A | newark | 26M5154 | - | - | 50 | v | 10 | % | ceramic | -
C1312 | 1nF | SM0805-C1 | avx | 08055F102K4Z2A | newark | 26M5154 | - | - | 50 | v | 10 | % | ceramic | -
C1313 | 100pF | SM0805-C1 | avx | 08051A101FAT2A | newark | 96M1317 | - | - | 100 | v | 1 | % | ceramic | -
C1314 | 100pF | SM0805-C1 | avx | 08051A101FAT2A | newark | 96M1317 | - | - | 100 | v | 1 | % | ceramic | -
C1315 | 33nF | SM0805-C1 | yageo | CC0805KRX7R8BB333 | newark | 69C9599 |  |  | 25V | 10% | ceramic | other | more | stuff
C1316 | 33nF | SM0805-C1 | yageo | CC0805KRX7R8BB333 | newark | 69C9599 |  |  | 25V | 10% | ceramic | other | more | stuff
C1317 | 0.1uF | SM0805-C1 | avx | 08051C104KAT2A | newark | 96M1354 |  |  | 100V | 10% | ceramic | other | more | stuff
C1318 | 1.5nF | SM0805 | Yageo | CC0805KRX7R9BB152 | digikey | 311-1128-1-ND | 50v | 10% | ceramic | other | more | stuff
C1319 | 0.1uF | SM0805-C1 | avx | 08051C104KAT2A | newark | 96M1354 |  |  | 100V | 10% | ceramic | other | more | stuff
C1320 | 1.5nF | SM0805 | Yageo | CC0805KRX7R9BB152 | digikey | 311-1128-1-ND | 50v | 10% | ceramic | other | more | stuff
C1321 | 0.1uF | SM0805-C1 | avx | 08051C104KAT2A | newark | 96M1354 |  |  | 100V | 10% | ceramic | other | more | stuff
C1322 | 10nF | SM0805-C1 | ill cap | 106CKE200M | newark | 69K7896 |  |  | 200V | 10% | alum elec | other | more | stuff
C1323 | 330pF | SM0805 | AVX | 08055C333KAZ2A | digikey | 478-3550-1-ND | 50 | 10% | ceramic | other | more | stuff
C1324 | 1uF | SM0805-C1 | avx | 08051C103JAT2A | newark | 96M1352 | - | - | 100 | v | 5 | % | ceramic | -
C1325 | 0.1uF | SM0805-C1 | avx | 08051C104KAT2A | newark | 96M1354 |  |  | 100V | 10% | ceramic | other | more | stuff
C1326 | 1uF | SM0805-C1 | avx | 08051C103JAT2A | newark | 96M1352 | - | - | 100 | v | 5 | % | ceramic | -
C1327 | 0.1uF | SM0805-C1 | avx | 08051C104KAT2A | newark | 96M1354 |  |  | 100V | 10% | ceramic | other | more | stuff
C1328 | 100nF | SM0805-C1 | avx | 08051C104KAT2A | newark | 96M1354 |  |  | 100V | 10% | ceramic | other | more | stuff
C1329 | 1nF | SM0805-C1 | avx | 08055F102K4Z2A | newark | 26M5154 | - | - | 50 | v | 10 | % | ceramic | -
C1330 | 100nF | SM0805-C1 | avx | 08051C104KAT2A | newark | 96M1354 |  |  | 100V | 10% | ceramic | other | more | stuff
C1331 | 1nF | SM0805-C1 | avx | 08055F102K4Z2A | newark | 26M5154 | - | - | 50 | v | 10 | % | ceramic | -
D101 | PESD1CAN | SOT23-3 | nxp | PESD1CAN | newark | 74M3585
D201 | LED | LED-0805 | OSRAM | LH R974-LP-1-0-20-R18 | DIGI | 475-1415-1-ND |  |  | .02A | -% | RED | other | more | stuff
D401 | MBR0520L | SOD-123 | fairchild | MBR0520L | mouser | 512-MBR0520L | - | - | - | - | 20 | V-reverse | .5 | A-forward | SMT | other | more | stuff
D402 | MBR0520L | SOD-123 | fairchild | MBR0520L | mouser | 512-MBR0520L | - | - | - | - | 20 | V-reverse | .5 | A-forward | SMT | other | more | stuff
D403 | MBR0520L | SOD-123 | fairchild | MBR0520L | mouser | 512-MBR0520L | - | - | - | - | 20 | V-reverse | .5 | A-forward | SMT | other | more | stuff
D404 | MBR0520L | SOD-123 | fairchild | MBR0520L | mouser | 512-MBR0520L | - | - | - | - | 20 | V-reverse | .5 | A-forward | SMT | other | more | stuff
D405 | MBR0520L | SOD-123 | fairchild | MBR0520L | mouser | 512-MBR0520L | - | - | - | - | 20 | V-reverse | .5 | A-forward | SMT | other | more | stuff
D406 | MBR0520L | SOD-123 | fairchild | MBR0520L | mouser | 512-MBR0520L | - | - | - | - | 20 | V-reverse | .5 | A-forward | SMT | other | more | stuff
D407 | MBR0520L | SOD-123 | fairchild | MBR0520L | mouser | 512-MBR0520L | - | - | - | - | 20 | V-reverse | .5 | A-forward | SMT | other | more | stuff
D408 | MBR0520L | SOD-123 | fairchild | MBR0520L | mouser | 512-MBR0520L | - | - | - | - | 20 | V-reverse | .5 | A-forward | SMT | other | more | stuff
D409 | MBR0520L | SOD-123 | fairchild | MBR0520L | mouser | 512-MBR0520L | - | - | - | - | 20 | V-reverse | .5 | A-forward | SMT | other | more | stuff
D410 | MBR0520L | SOD-123 | fairchild | MBR0520L | mouser | 512-MBR0520L | - | - | - | - | 20 | V-reverse | .5 | A-forward | SMT | other | more | stuff
D411 | MBR0520L | SOD-123 | fairchild | MBR0520L | mouser | 512-MBR0520L | - | - | - | - | 20 | V-reverse | .5 | A-forward | SMT | other | more | stuff
D412 | MBR0520L | SOD-123 | fairchild | MBR0520L | mouser | 512-MBR0520L | - | - | - | - | 20 | V-reverse | .5 | A-forward | SMT | other | more | stuff
D413 | MBR0520L | SOD-123 | fairchild | MBR0520L | mouser | 512-MBR0520L | - | - | - | - | 20 | V-reverse | .5 | A-forward | SMT | other | more | stuff
D414 | MBR0520L | SOD-123 | fairchild | MBR0520L | mouser | 512-MBR0520L | - | - | - | - | 20 | V-reverse | .5 | A-forward | SMT | other | more | stuff
D415 | MBR0520L | SOD-123 | fairchild | MBR0520L | mouser | 512-MBR0520L | - | - | - | - | 20 | V-reverse | .5 | A-forward | SMT | other | more | stuff
D416 | MBR0520L | SOD-123 | fairchild | MBR0520L | mouser | 512-MBR0520L | - | - | - | - | 20 | V-reverse | .5 | A-forward | SMT | other | more | stuff
D417 | MBR0520L | SOD-123 | fairchild | MBR0520L | mouser | 512-MBR0520L | - | - | - | - | 20 | V-reverse | .5 | A-forward | SMT | other | more | stuff
D418 | MBR0520L | SOD-123 | fairchild | MBR0520L | mouser | 512-MBR0520L | - | - | - | - | 20 | V-reverse | .5 | A-forward | SMT | other | more | stuff
D419 | MBR0520L | SOD-123 | fairchild | MBR0520L | mouser | 512-MBR0520L | - | - | - | - | 20 | V-reverse | .5 | A-forward | SMT | other | more | stuff
D420 | MBR0520L | SOD-123 | fairchild | MBR0520L | mouser | 512-MBR0520L | - | - | - | - | 20 | V-reverse | .5 | A-forward | SMT | other | more | stuff
D421 | MBR0520L | SOD-123 | fairchild | MBR0520L | mouser | 512-MBR0520L | - | - | - | - | 20 | V-reverse | .5 | A-forward | SMT | other | more | stuff
D422 | MBR0520L | SOD-123 | fairchild | MBR0520L | mouser | 512-MBR0520L | - | - | - | - | 20 | V-reverse | .5 | A-forward | SMT | other | more | stuff
D423 | MBR0520L | SOD-123 | fairchild | MBR0520L | mouser | 512-MBR0520L | - | - | - | - | 20 | V-reverse | .5 | A-forward | SMT | other | more | stuff
D424 | MBR0520L | SOD-123 | fairchild | MBR0520L | mouser | 512-MBR0520L | - | - | - | - | 20 | V-reverse | .5 | A-forward | SMT | other | more | stuff
D425 | MBR0520L | SOD-123 | fairchild | MBR0520L | mouser | 512-MBR0520L | - | - | - | - | 20 | V-reverse | .5 | A-forward | SMT | other | more | stuff
D426 | MBR0520L | SOD-123 | fairchild | MBR0520L | mouser | 512-MBR0520L | - | - | - | - | 20 | V-reverse | .5 | A-forward | SMT | other | more | stuff
D427 | MBR0520L | SOD-123 | fairchild | MBR0520L | mouser | 512-MBR0520L | - | - | - | - | 20 | V-reverse | .5 | A-forward | SMT | other | more | stuff
D428 | MBR0520L | SOD-123 | fairchild | MBR0520L | mouser | 512-MBR0520L | - | - | - | - | 20 | V-reverse | .5 | A-forward | SMT | other | more | stuff
D701 | LED | LED-0805 | OSRAM | LH R974-LP-1-0-20-R18 | DIGI | 475-1415-1-ND |  |  | .02A | -% | RED | other | more | stuff
D702 | STTH4R02S | D4-SMB | st | STTH4R02U | newark | 26M3786 | - | - | - | -
D703 | TPSMA27A | DO214 | vishay | TPSMA27A-E3/61T | mouser | 625-TPSMA27A-E3 | 37.5 | 10.7 | - | -
D704 | Schottky | SOD-123 | Micro Commercial Co | 1N4148W-TP | digikey | 1N4148WTPMSCT-ND | .15a | -% | standard | other | more | stuff
D705 | Schottky | SOD-123 | Micro Commercial Co | 1N4148W-TP | digikey | 1N4148WTPMSCT-ND | .15a | -% | standard | other | more | stuff
D706 | 5v1 | SOD-123
D707 | 1N4148 | SOD-123 | Micro Commercial Co | 1N4148W-TP | digikey | 1N4148WTPMSCT-ND | .15a | -% | standard | other | more | stuff
D708 | STPS5L25 | D4-SMB | STPS5L25B-TR | st | 511-STPS2L25U | mouser | 511-STPS2L25U | - | - | - | - | 25 | V | 2 | a | construct | other | more | stuff
D801 | DIODE | D4-SMB | stmicro | STPS340U | quest | STPS340U
D802 | DIODE | D4-SMB | stmicro | STPS340U | quest | STPS340U
D803 | DIODE | D4-SMB | stmicro | STPS340U | quest | STPS340U
D804 | DIODE | D4-SMB | stmicro | STPS340U | quest | STPS340U
D805 | DIODE | D4-SMB | stmicro | STPS340U | quest | STPS340U
D806 | DIODE | D4-SMB | stmicro | STPS340U | quest | STPS340U
D807 | DIODE | D4-SMB | stmicro | STPS340U | quest | STPS340U
D808 | DIODE | D4-SMB | stmicro | STPS340U | quest | STPS340U
D1001 | MBRA340T3 | D4-SMA | onsemi | MBRA340T3G | mouser | 863-MBRA340T3G | - | - | - | - | .45 | V | 3 | a | - | other | more | stuff
D1002 | MBRA340T3 | D4-SMA | onsemi | MBRA340T3G | mouser | 863-MBRA340T3G | - | - | - | - | .45 | V | 3 | a | - | other | more | stuff
D1301 | MBR0520L | SOD-123 | fairchild | MBR0520L | mouser | 512-MBR0520L | - | - | - | - | 20 | V-reverse | .5 | A-forward | SMT | other | more | stuff
D1302 | MBR0520L | SOD-123 | fairchild | MBR0520L | mouser | 512-MBR0520L | - | - | - | - | 20 | V-reverse | .5 | A-forward | SMT | other | more | stuff
D1303 | MBR0520L | SOD-123 | fairchild | MBR0520L | mouser | 512-MBR0520L | - | - | - | - | 20 | V-reverse | .5 | A-forward | SMT | other | more | stuff
D1304 | MBR0520L | SOD-123 | fairchild | MBR0520L | mouser | 512-MBR0520L | - | - | - | - | 20 | V-reverse | .5 | A-forward | SMT | other | more | stuff
D1305 | MBR0520L | SOD-123 | fairchild | MBR0520L | mouser | 512-MBR0520L | - | - | - | - | 20 | V-reverse | .5 | A-forward | SMT | other | more | stuff
D1306 | MBR0520L | SOD-123 | fairchild | MBR0520L | mouser | 512-MBR0520L | - | - | - | - | 20 | V-reverse | .5 | A-forward | SMT | other | more | stuff
J301 | MOLEX_HARNESS_SD-64333-100 | Molex_SD-64333-100_on_Cinch_ModICE_w_5554_SOM_con-only
L701 | 4.7uH | SM4.7uH | coiltronics | UP0.4C-4R7-R | newark | 52K7863 | - | - | - | - | 1.5 | a | 20 | % | construct | other | more | stuff
L702 | DR125-330-R | SM100uH | coiltronics | DR125-330-R | digi | 513-1528-6-ND |  |  | 33uH | 20% | ferrite | other | more | stuff
P101 | CONN_1 | PINTST
P102 | CONN_1 | PINTST
P103 | CONN_1 | PINTST
P104 | CONN_1 | PINTST
P105 | CONN_1 | PINTST
P106 | CONN_1 | PINTST
P107 | CONN_1 | PINTST
P108 | CONN_1 | PINTST
P109 | CONN_1 | PINTST
P110 | CONN_1 | PINTST
P111 | CONN_1 | PINTST
P112 | CONN_1 | PINTST
P113 | CONN_1 | PINTST
P114 | CONN_1 | PINTST
P115 | CONN_1 | PINTST
P116 | CONN_1 | PINTST
P117 | CONN_1 | PINTST
P118 | CONN_1 | PINTST
P119 | CONN_1 | PINTST
P120 | CONN_1 | PINTST
P121 | CONN_1 | PINTST
P122 | CONN_1 | PINTST
P123 | CONN_1 | PINTST
P124 | CONN_1 | PINTST
P125 | CONN_1 | PINTST
P126 | CONN_1 | PINTST
P127 | CONN_1 | PINTST
P201 | MPC5554 | phyCORE-MPC5554
P601 | CONN_1 | PINTST
P602 | CONN_1 | PINTST
P603 | CONN_1 | PINTST
P604 | CONN_1 | PINTST
P605 | CONN_1 | PINTST
P606 | CONN_1 | PINTST
P607 | CONN_1 | PINTST
P608 | CONN_1 | PINTST
P609 | CONN_1 | PINTST
P610 | CONN_1 | PINTST
P611 | CONN_1 | PINTST
P612 | CONN_1 | PINTST
P613 | CONN_1 | PINTST
P614 | CONN_1 | PINTST
P615 | CONN_1 | PINTST
P616 | CONN_1 | PINTST
P801 | CONN_1 | PINTST
P802 | CONN_1 | PINTST
P803 | CONN_1 | PINTST
P804 | CONN_1 | PINTST
P805 | CONN_1 | PINTST
P901 | CONN_1 | PINTST
P902 | CONN_1 | PINTST
P903 | CONN_1 | PINTST
P904 | CONN_1 | PINTST
P1001 | CONN_1 | PINTST
P1002 | CONN_1 | PINTST
P1003 | CONN_1 | PINTST
P1004 | CONN_1 | PINTST
P1005 | CONN_1 | PINTST
P1006 | CONN_1 | PINTST
P1007 | CONN_1 | PINTST
P1008 | CONN_1 | PINTST
P1009 | CONN_1 | PINTST
P1010 | CONN_1 | PINTST
P1011 | CONN_1 | PINTST
P1012 | CONN_1 | PINTST
P1013 | CONN_1 | PINTST
P1014 | CONN_1 | PINTST
P1015 | CONN_1 | PINTST
P1016 | CONN_1 | PINTST
P1017 | CONN_1 | PINTST
P1018 | CONN_1 | PINTST
P1019 | CONN_1 | PINTST
P1020 | CONN_1 | PINTST
P1021 | CONN_1 | PINTST
P1022 | CONN_1 | PINTST
P1023 | CONN_1 | PINTST
P1024 | CONN_1 | PINTST
P1025 | CONN_1 | PINTST
P1026 | CONN_1 | PINTST
P1027 | CONN_1 | PINTST
P1028 | CONN_1 | PINTST
P1029 | CONN_1 | PINTST
P1030 | CONN_1 | PINTST
P1031 | CONN_1 | PINTST
P1101 | CONN_1 | PINTST
P1102 | CONN_1 | PINTST
P1201 | CONN_1 | PINTST
P1202 | CONN_1 | PINTST
P1203 | CONN_1 | PINTST
P1204 | CONN_1 | PINTST
P1205 | CONN_1 | PINTST
P1206 | CONN_1 | PINTST
P1207 | CONN_1 | PINTST
P1208 | CONN_1 | PINTST
P1209 | CONN_1 | PINTST
P1210 | CONN_1 | PINTST
P1211 | CONN_1 | PINTST
P1212 | CONN_1 | PINTST
P1301 | CONN_1 | PINTST
P1302 | CONN_1 | PINTST
P1303 | CONN_1 | PINTST
P1304 | CONN_1 | PINTST
Q501 | OVP_DRIVER | SO8E_ST | ST | VNS14NV04 | newark | 33R1503 |  |  | 12A | 40V | OVP MOSFET | other | more | stuff
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

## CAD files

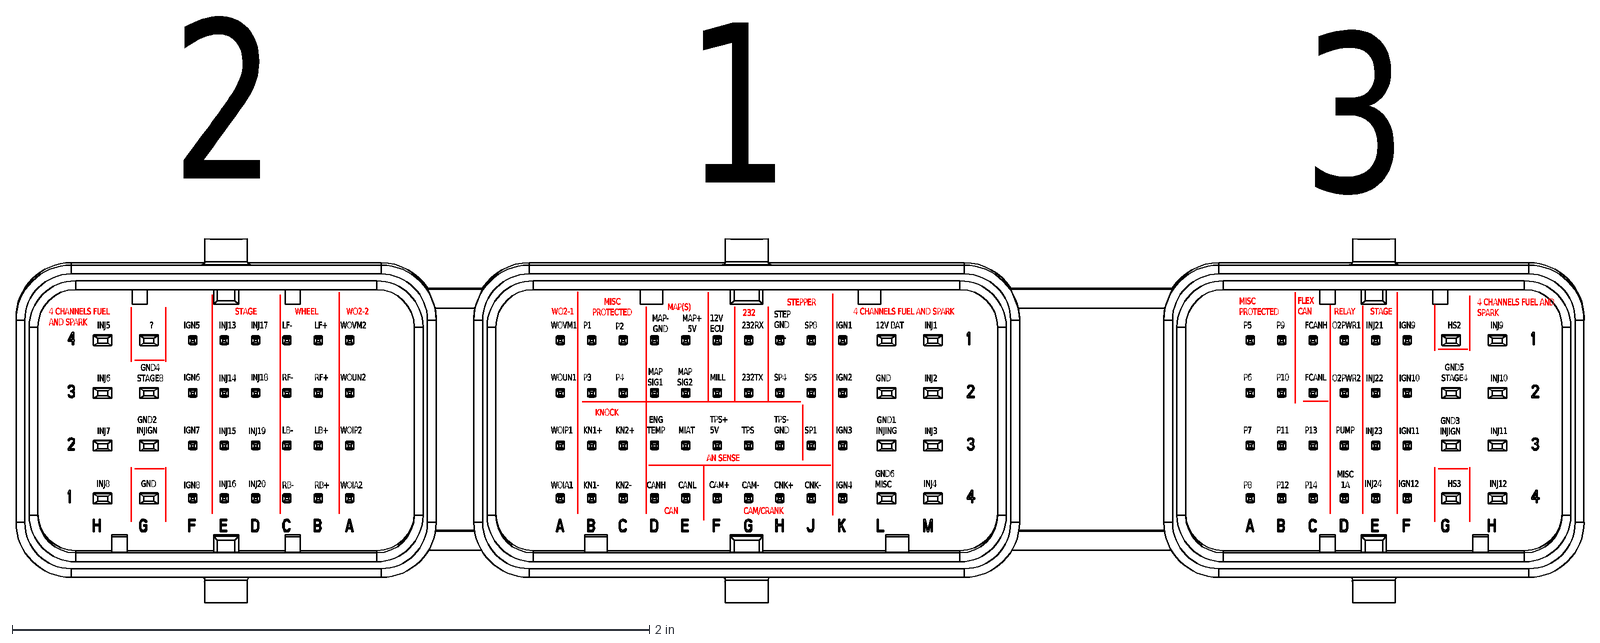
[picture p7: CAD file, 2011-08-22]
3D_stuff/harness_pinout.dxf
1
2
3
?
INJ5
GND4 STAGE8
INJ6
GND2 INJIGN
INJ7
GND
INJ8
LF-
IGN5
LF+
IGN6
RF-
RF+
IGN7
LB-
LB+
IGN8
RB-
RB+
INJ9
INJ10
INJ11
INJ12
GND3 INJIGN
INJ1
INJ2
INJ3
INJ4
12V BAT
GND1 INJING
GND6 MISC
FCANH
FCANL
P13
P14
INJ17
INJ18
PUMP
MISC 1A
WOVM2
WOUN2
WOIP2
WOIA2
WOIA1
WOIP1
WOUN1
WOVM1
P1
P3
KN1+
KN1-
P2
P4
KN2+
KN2-
MAP- GND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

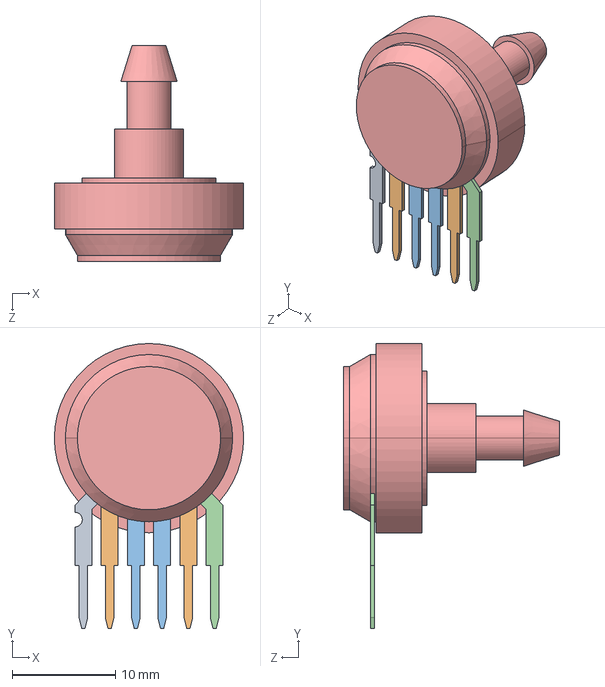
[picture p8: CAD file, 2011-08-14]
KICAD_Project/PCB-modules/MPX4100A/UNIBODY_STOVEPIPE.STEP
18.3 x 27.6 x 20.9 mm

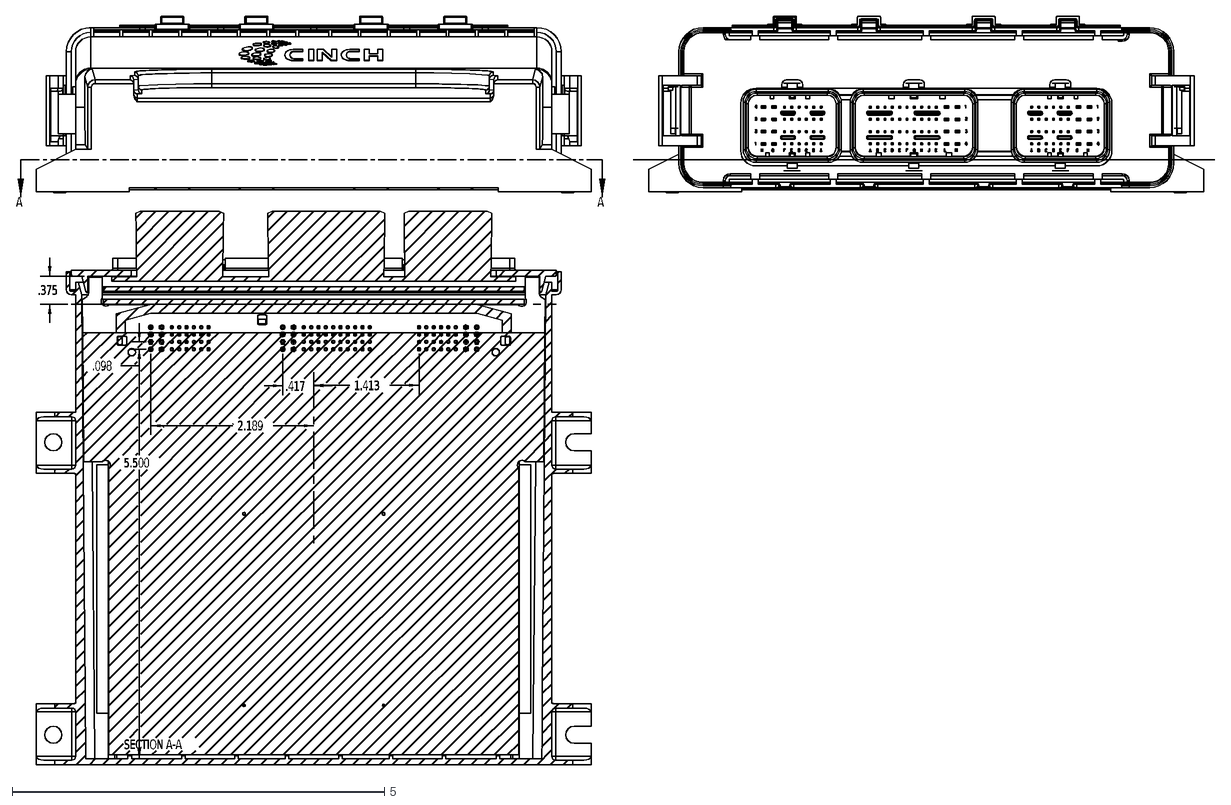
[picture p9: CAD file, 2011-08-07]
3D_stuff/ModeICE_case.DXF
A
5.500
.098
2.189
.417
1.413
.375
SECTION A-A

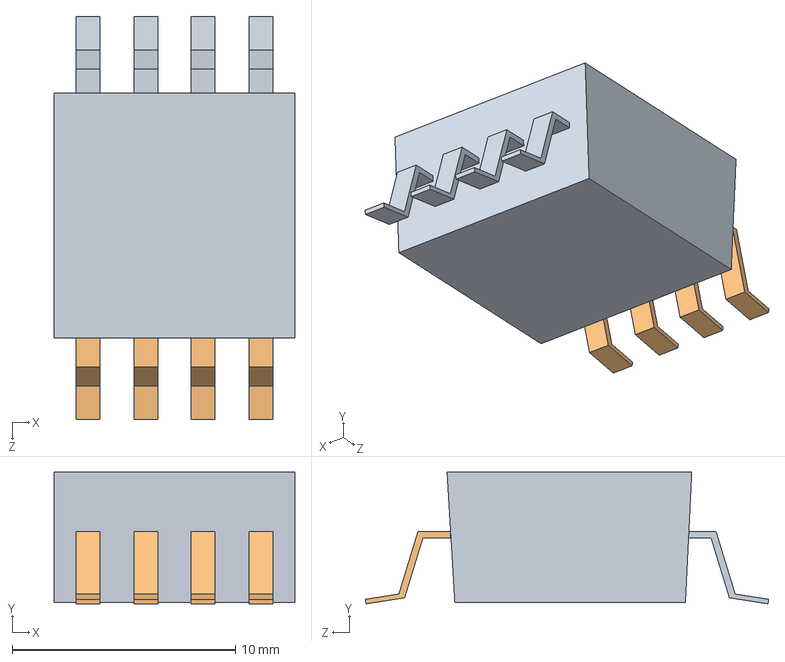
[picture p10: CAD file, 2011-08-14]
KICAD_Project/PCB-modules/MPX4100A/UNIBODY_SMT.STEP
10.8 x 5.90 x 18.1 mm

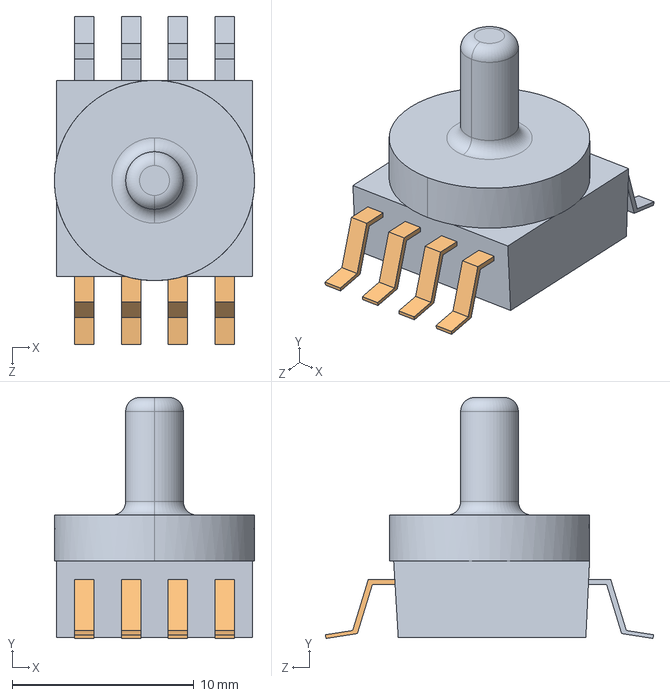
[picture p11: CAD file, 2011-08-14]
KICAD_Project/PCB-modules/MPX4100A/UNIBODY_SMALL-SMT.STEP
11.0 x 13.3 x 18.1 mm

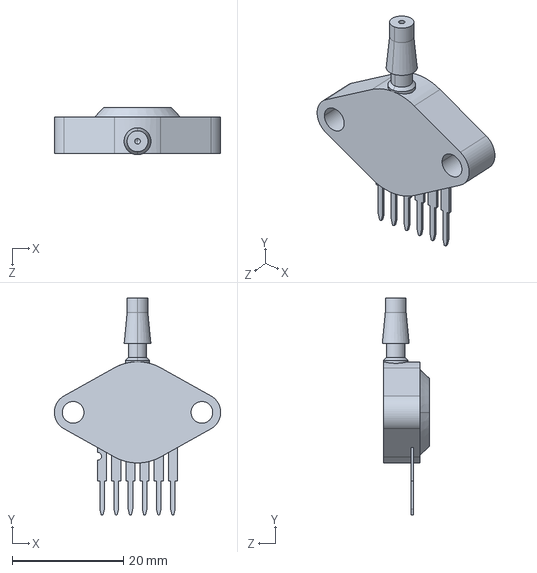
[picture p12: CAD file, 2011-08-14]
KICAD_Project/PCB-modules/MPX4100A/UNIBODY_CELL.STEP
29.8 x 38.9 x 8.51 mm

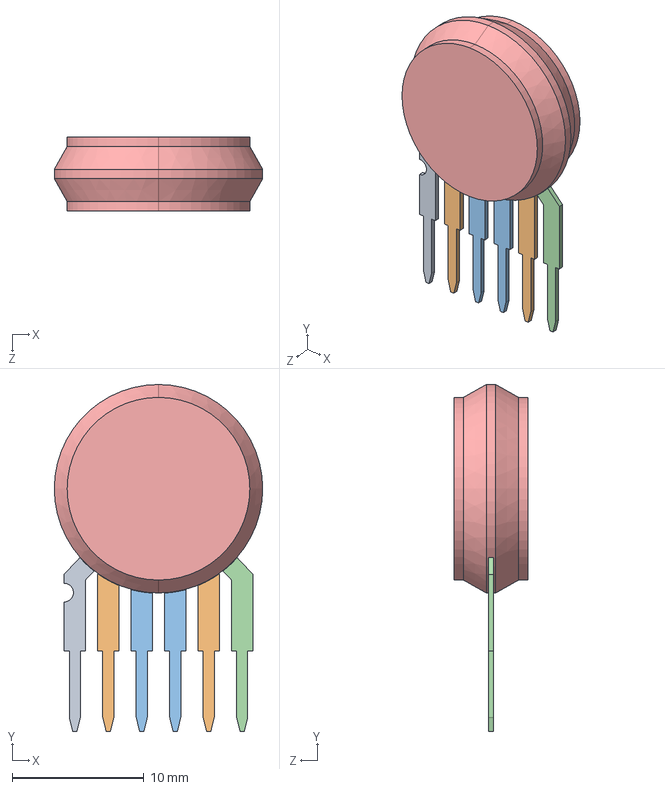
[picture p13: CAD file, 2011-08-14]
KICAD_Project/PCB-modules/MPX4100A/UNIBODY.STEP
15.8 x 26.3 x 5.59 mm

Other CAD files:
KICAD_Project/PCB-modules/MPX4100A/UNIBODY.SLDDRW
KICAD_Project/PCB-modules/MPX4100A/UNIBODY.SLDPRT
KICAD_Project/PCB-modules/MPX4100A/UNIBODY.STL
KICAD_Project/PCB-modules/MPX4100A/UNIBODY_CELL.SLDDRW
KICAD_Project/PCB-modules/MPX4100A/UNIBODY_CELL.SLDPRT
KICAD_Project/PCB-modules/MPX4100A/UNIBODY_CELL.STL
KICAD_Project/PCB-modules/MPX4100A/UNIBODY_SMALL-SMT.SLDPRT
KICAD_Project/PCB-modules/MPX4100A/UNIBODY_SMALL-SMT.STL
KICAD_Project/PCB-modules/MPX4100A/UNIBODY_SMT.SLDPRT
KICAD_Project/PCB-modules/MPX4100A/UNIBODY_SMT.STL
KICAD_Project/PCB-modules/MPX4100A/UNIBODY_STOVEPIPE.SLDDRW
KICAD_Project/PCB-modules/MPX4100A/UNIBODY_STOVEPIPE.SLDPRT
KICAD_Project/PCB-modules/MPX4100A/UNIBODY_STOVEPIPE.STL

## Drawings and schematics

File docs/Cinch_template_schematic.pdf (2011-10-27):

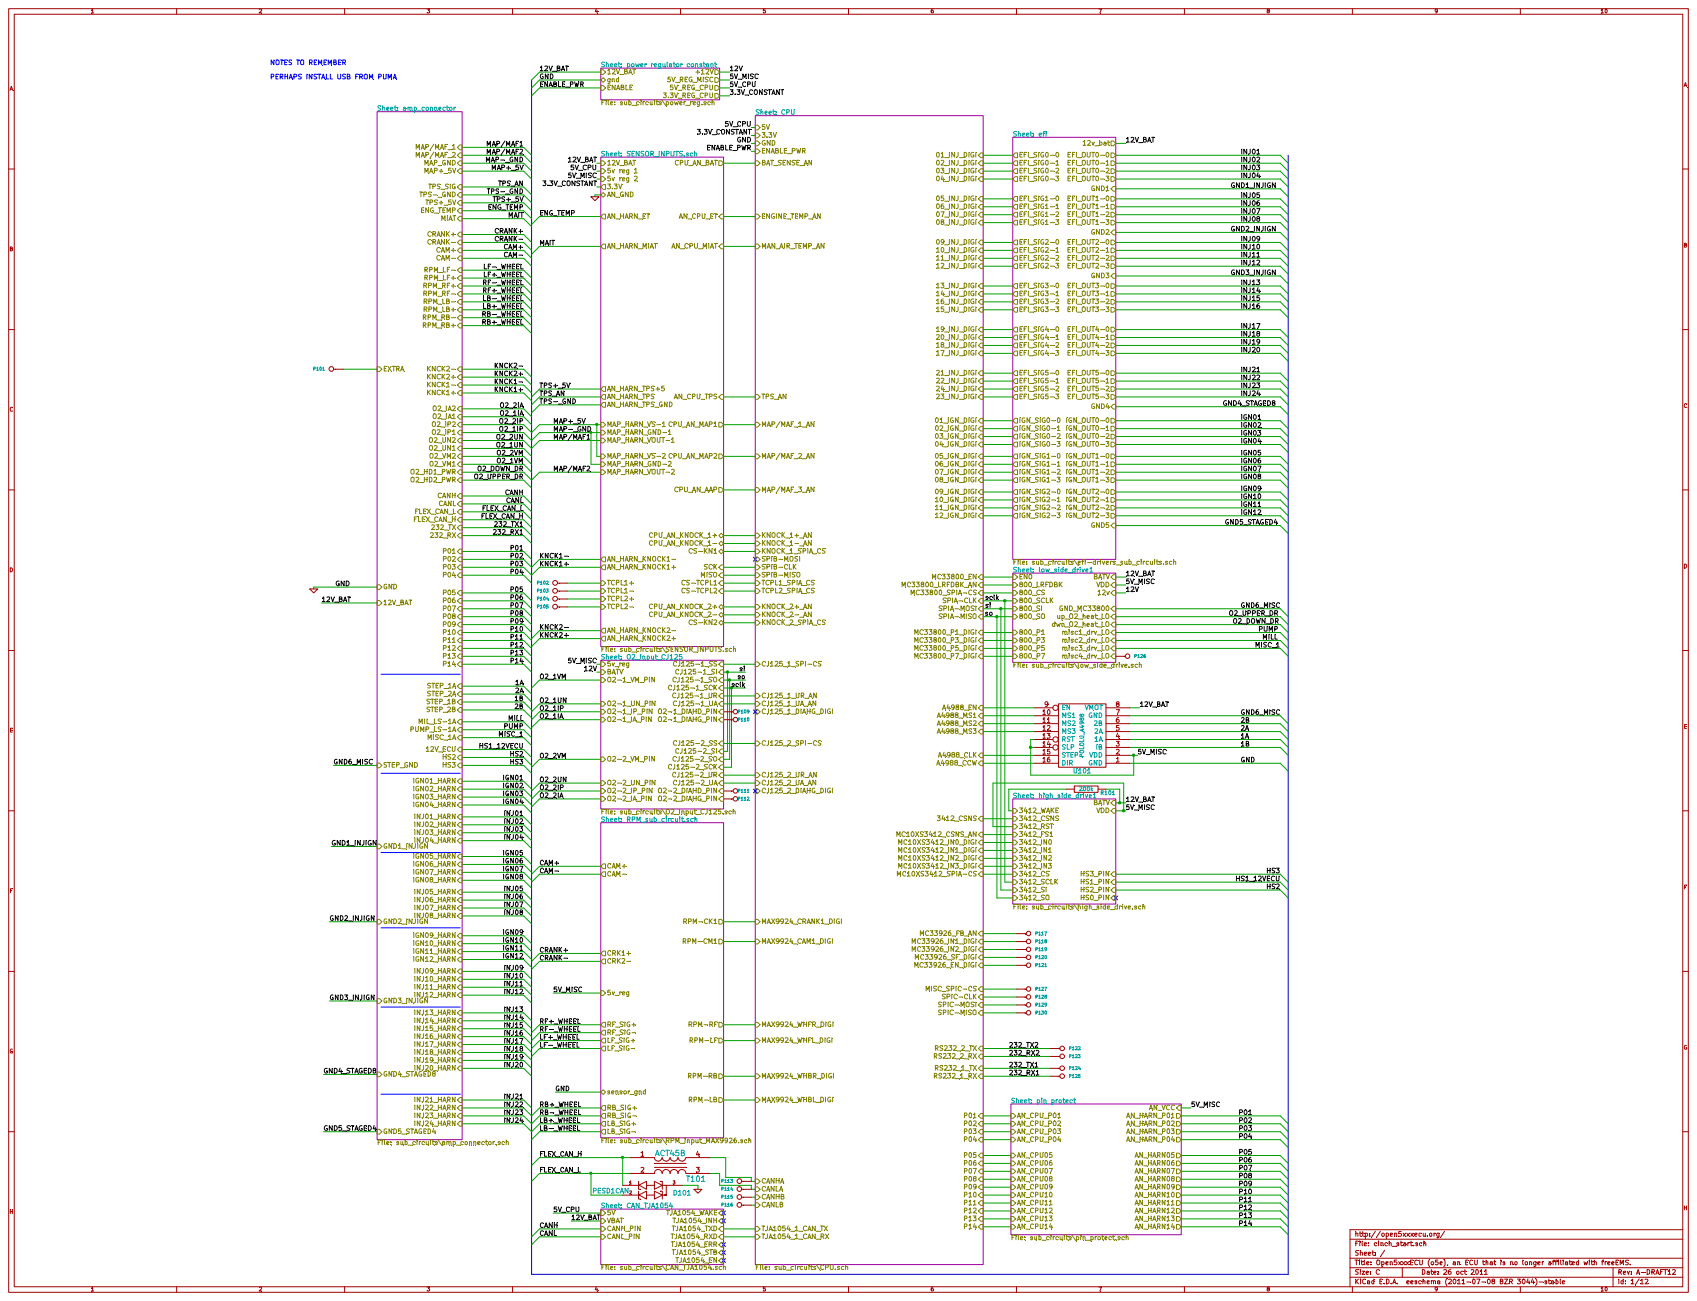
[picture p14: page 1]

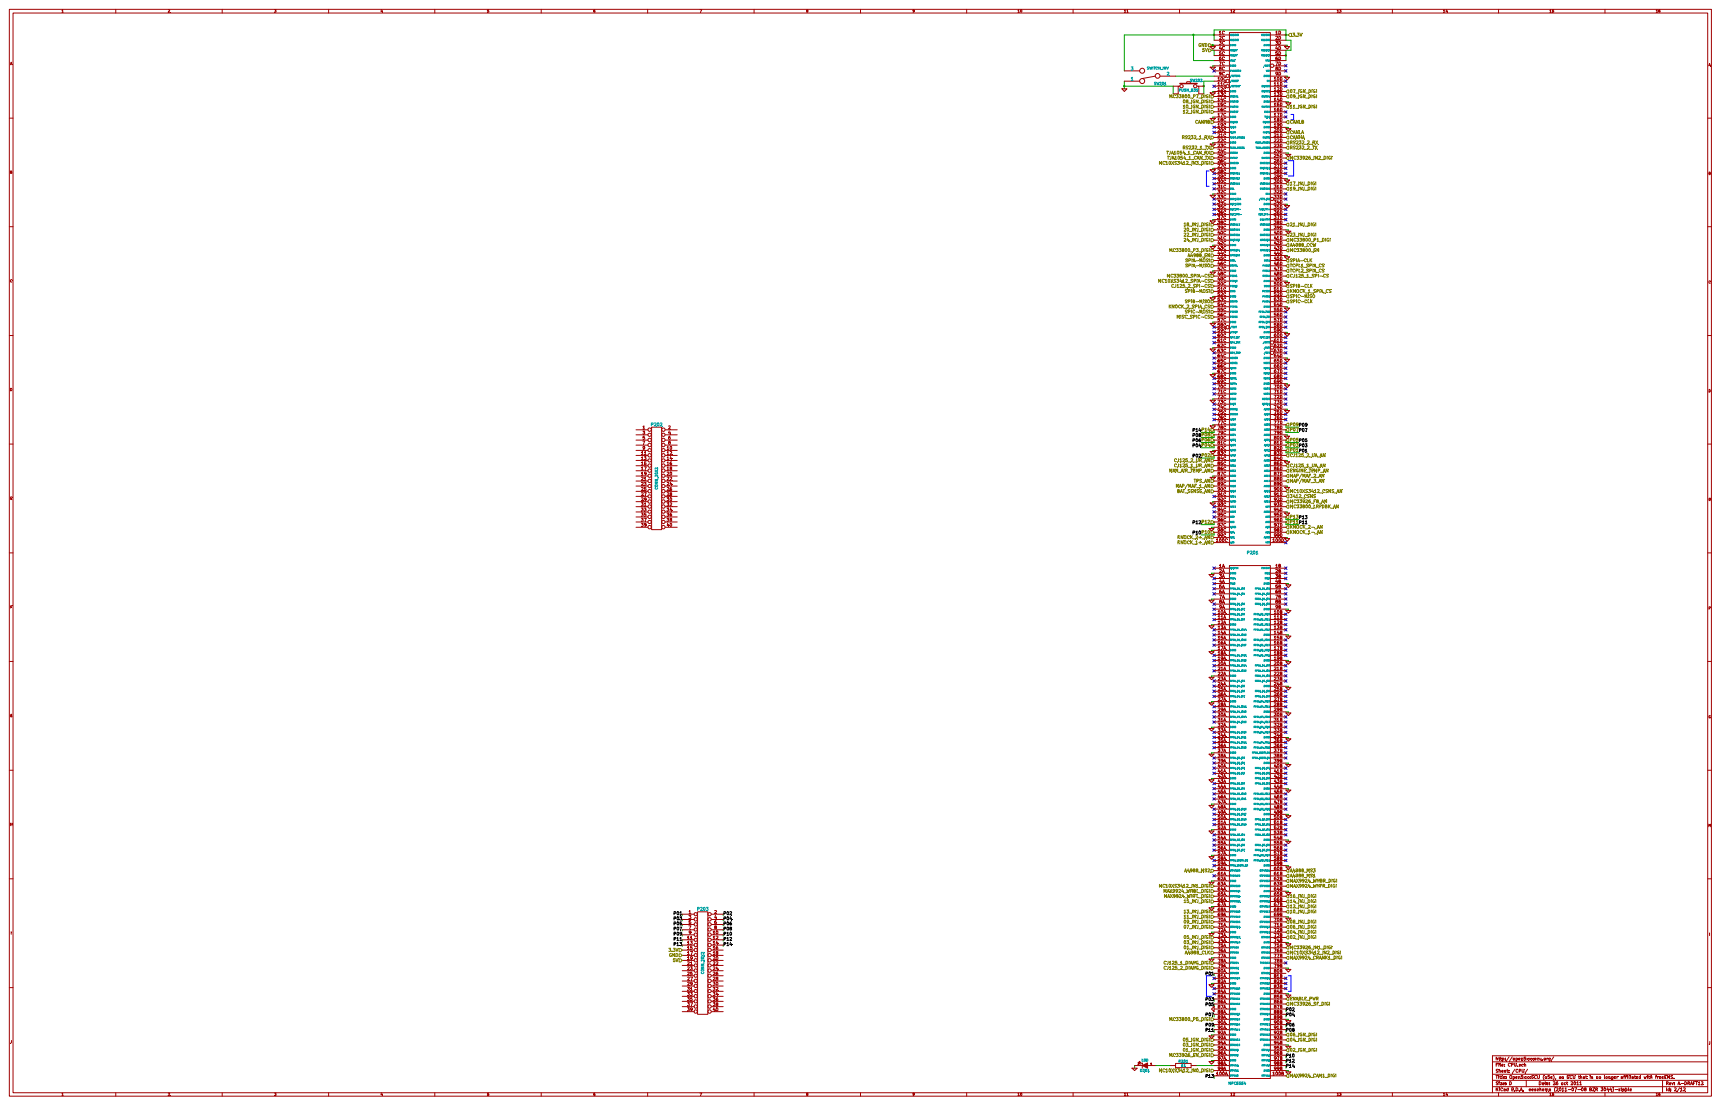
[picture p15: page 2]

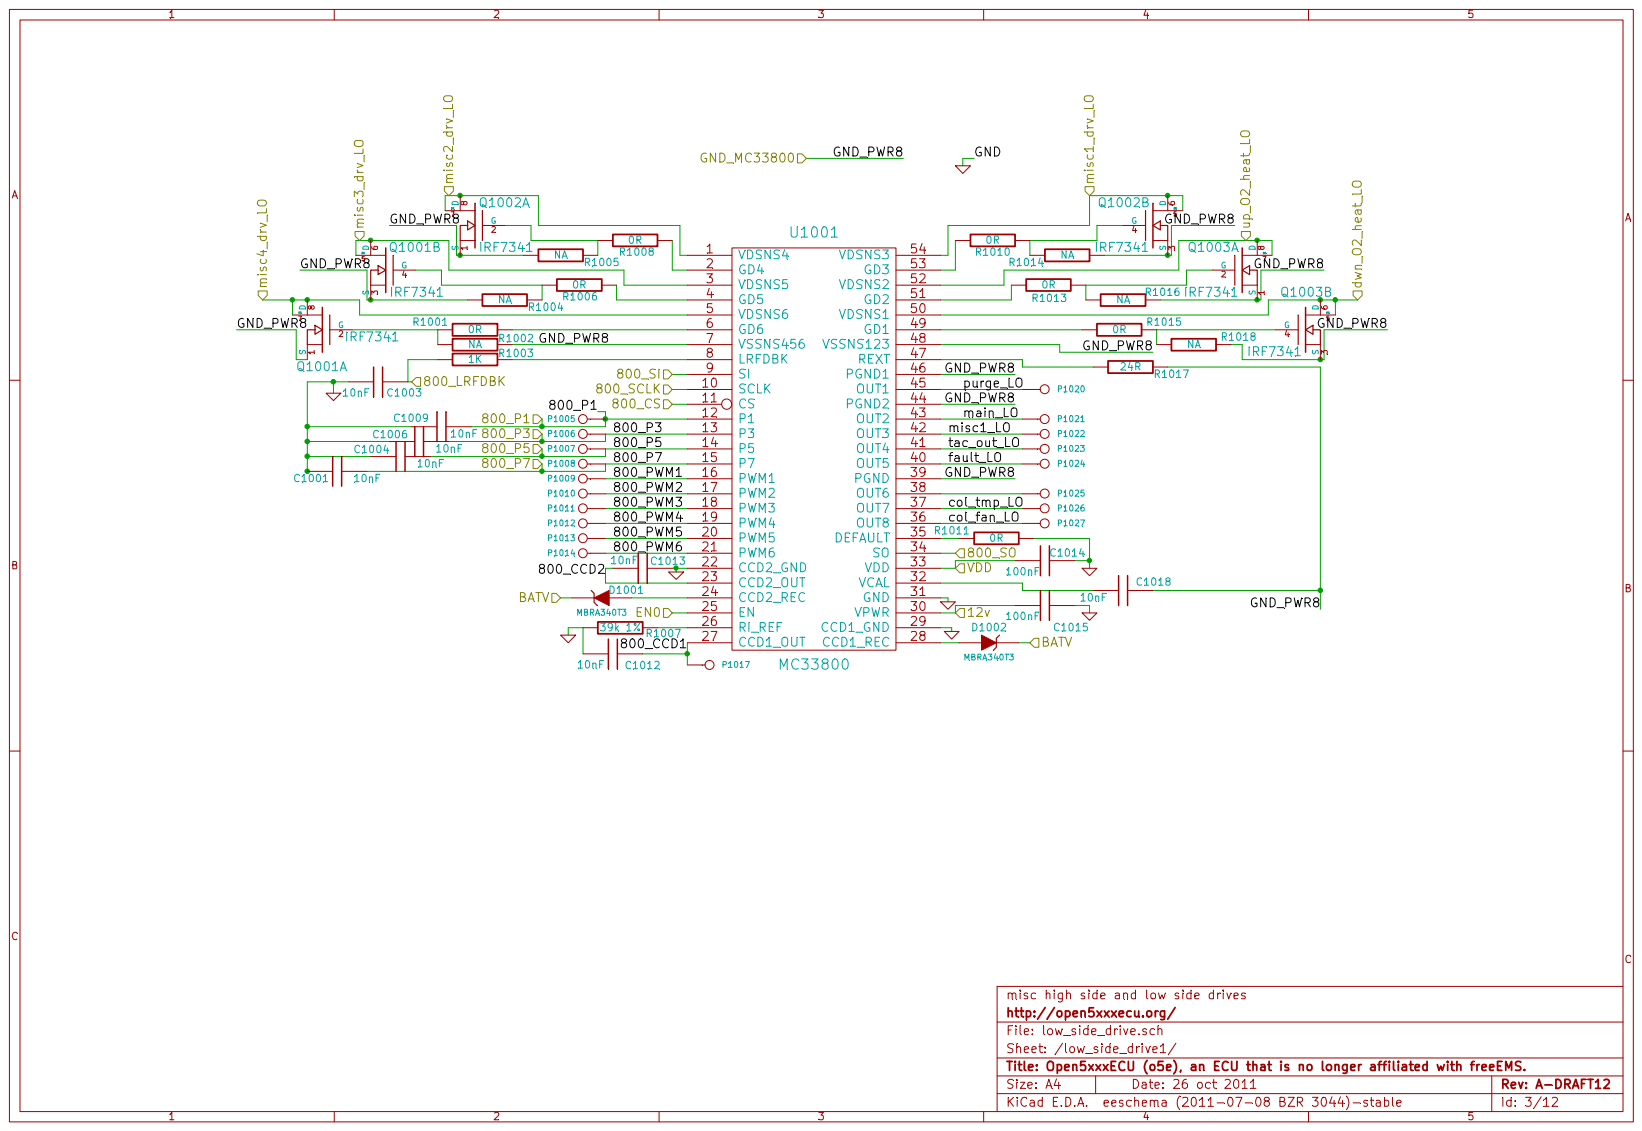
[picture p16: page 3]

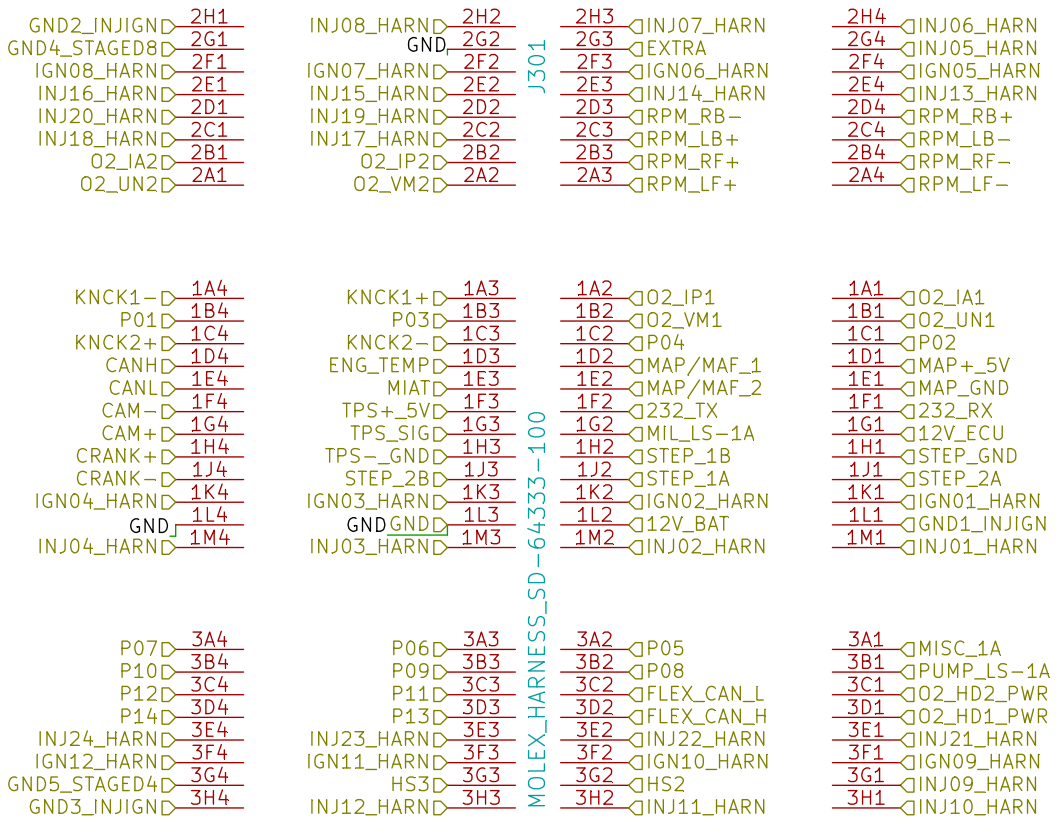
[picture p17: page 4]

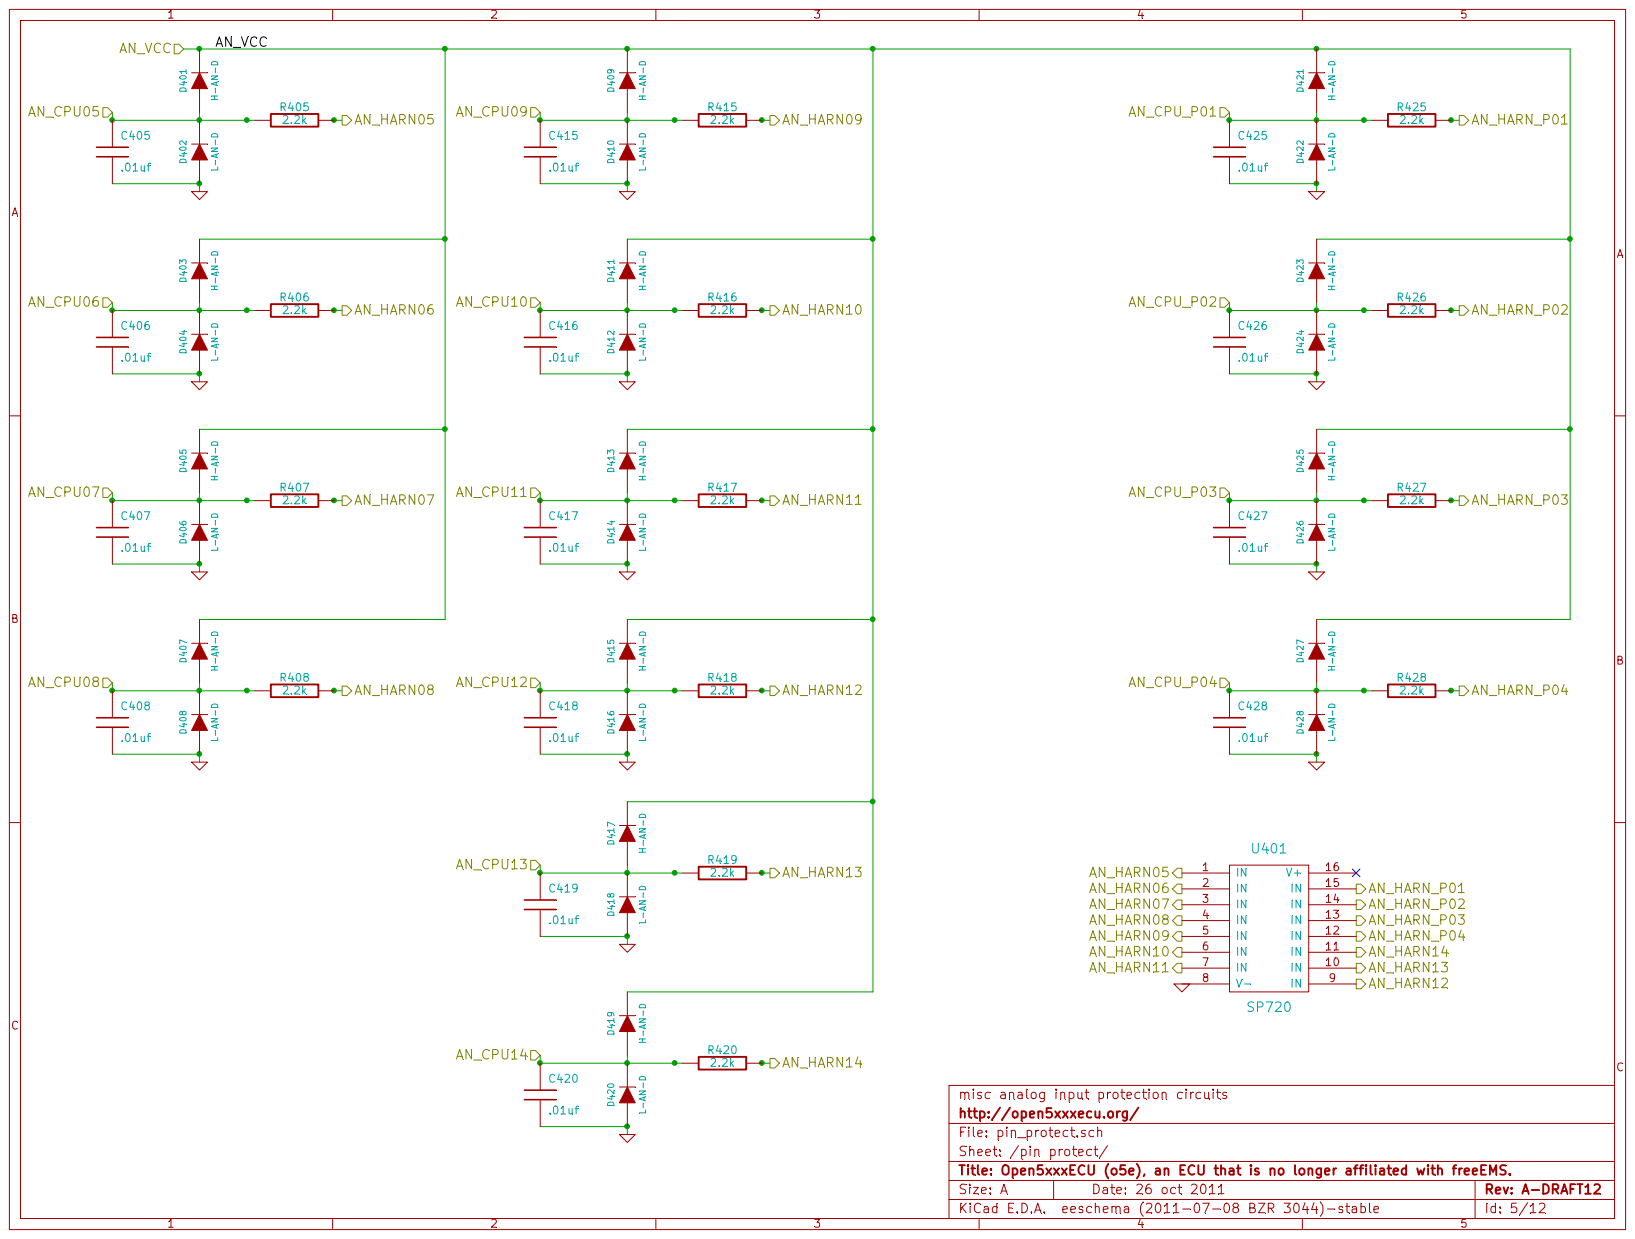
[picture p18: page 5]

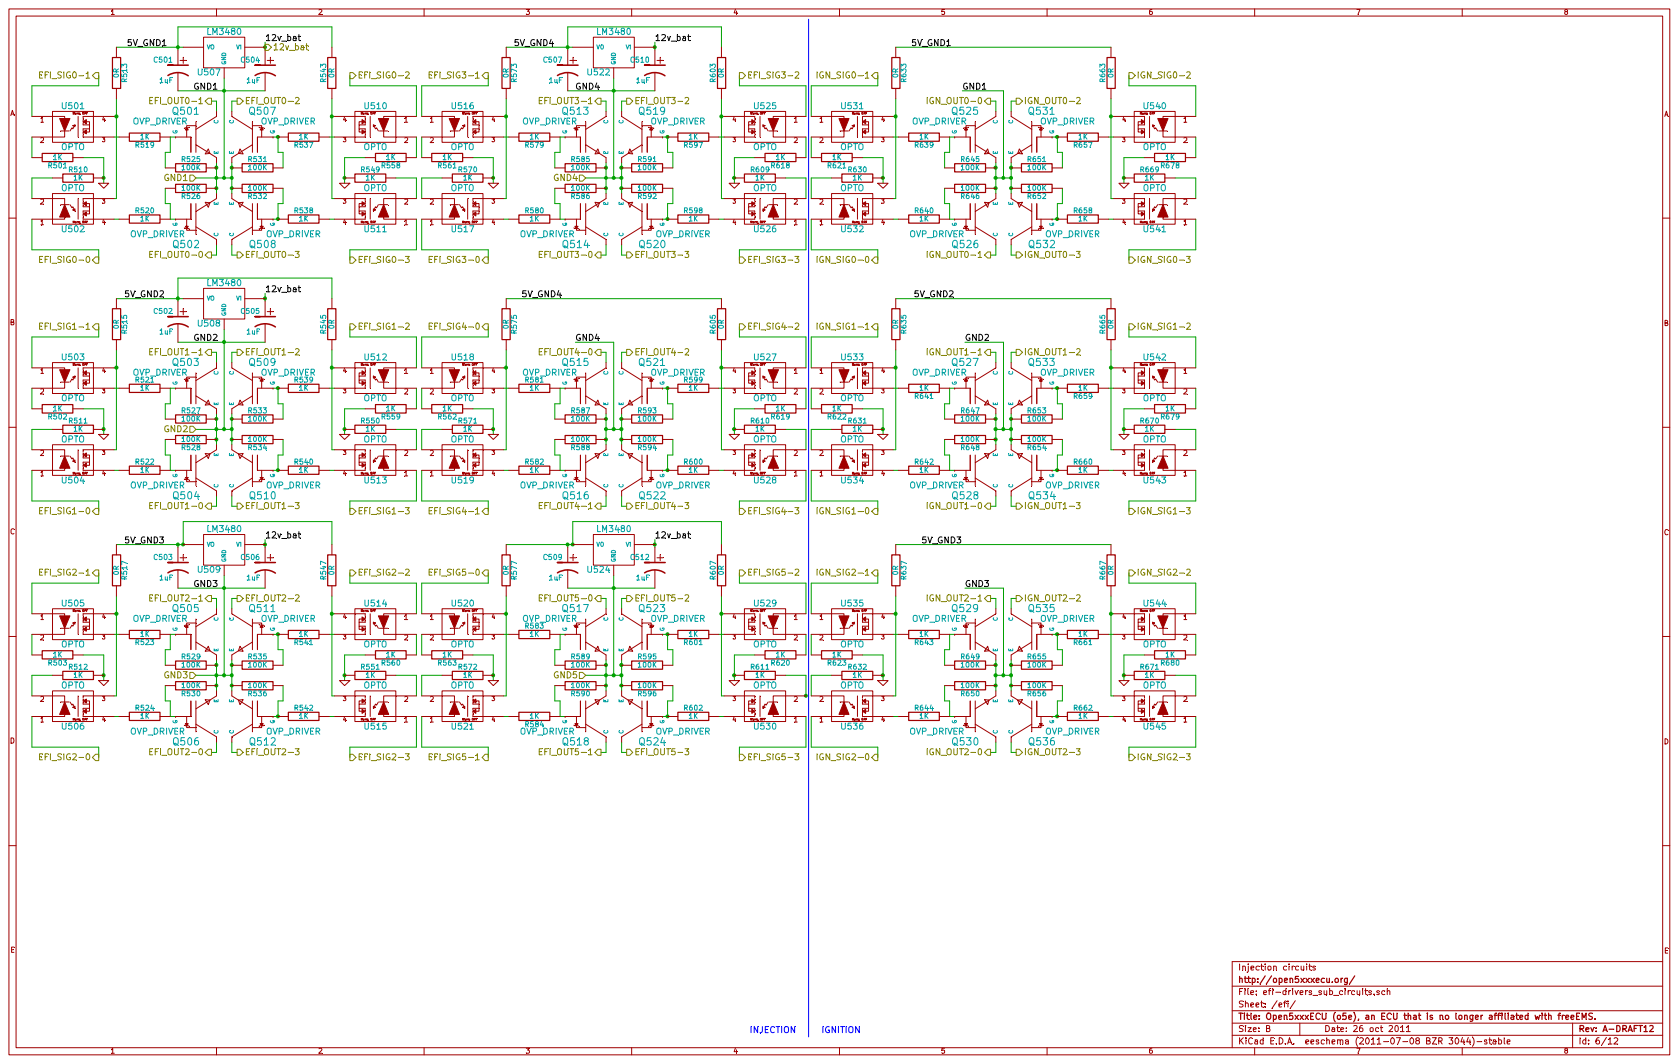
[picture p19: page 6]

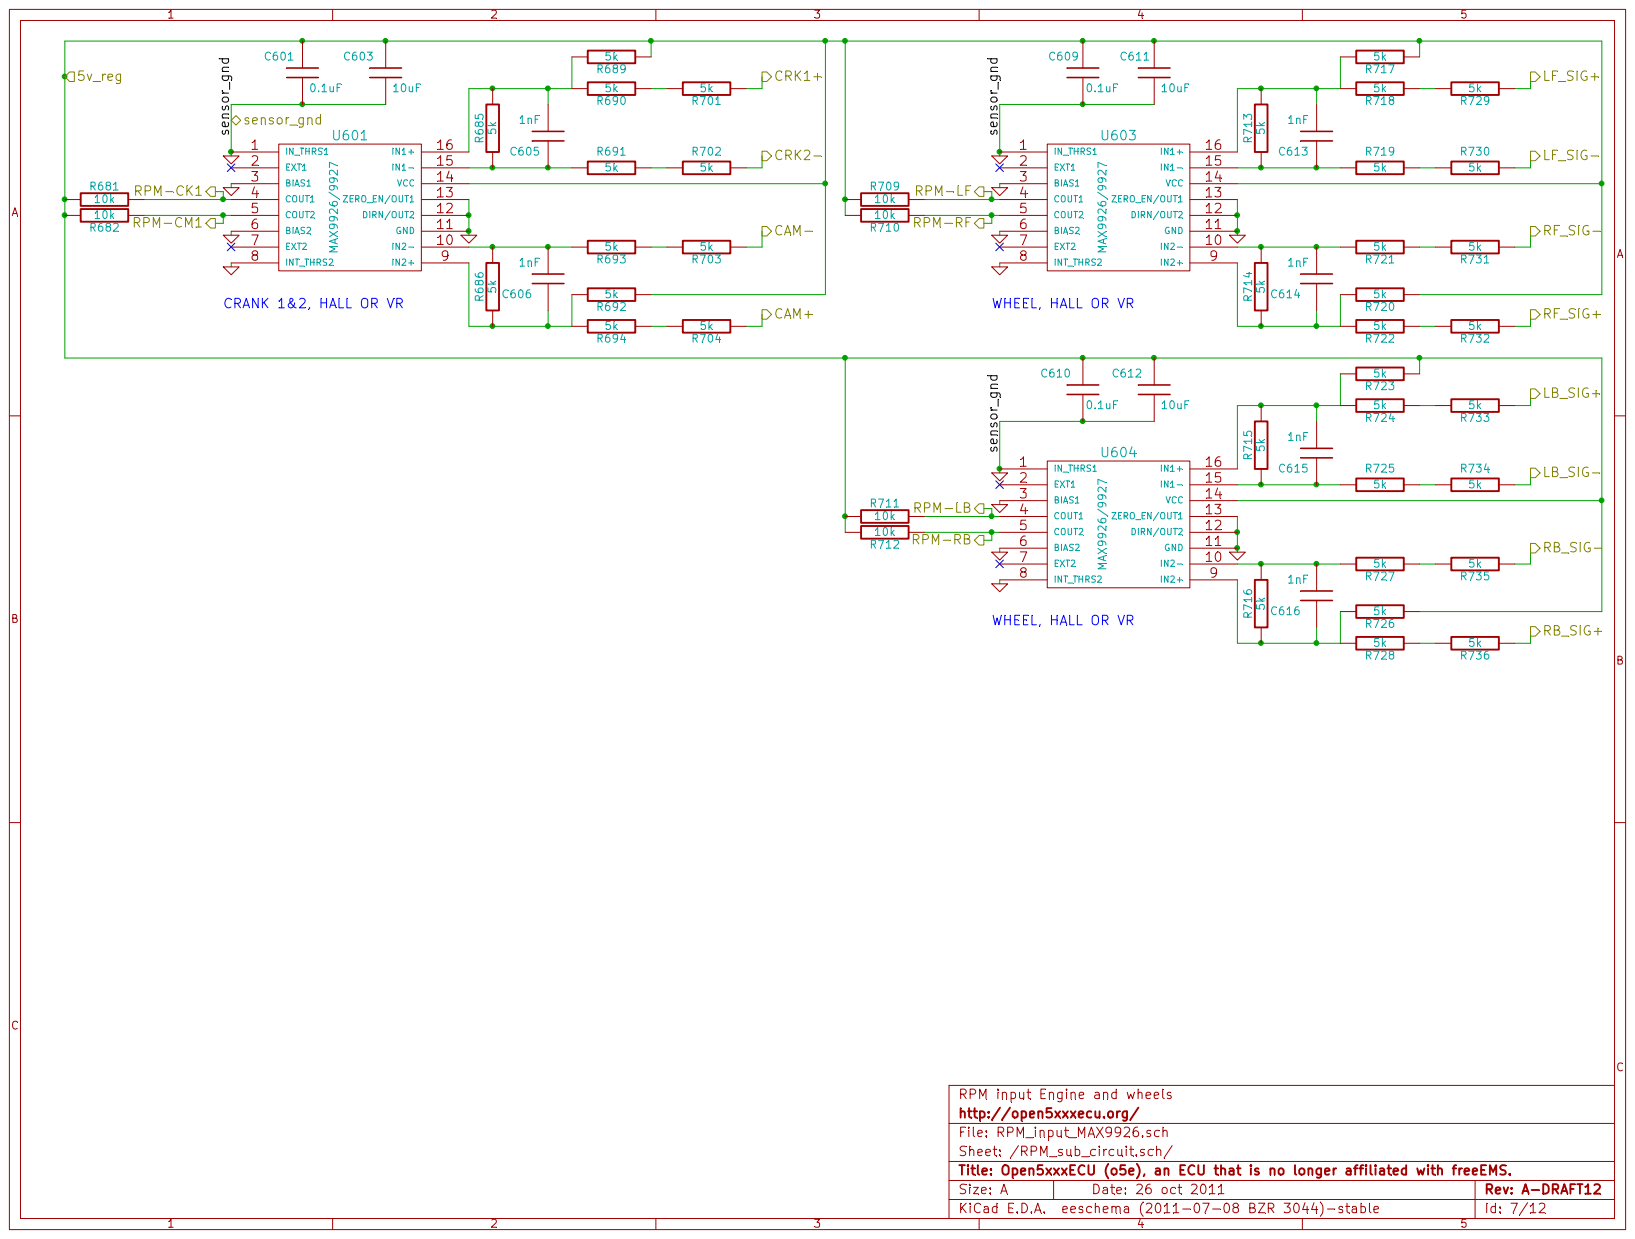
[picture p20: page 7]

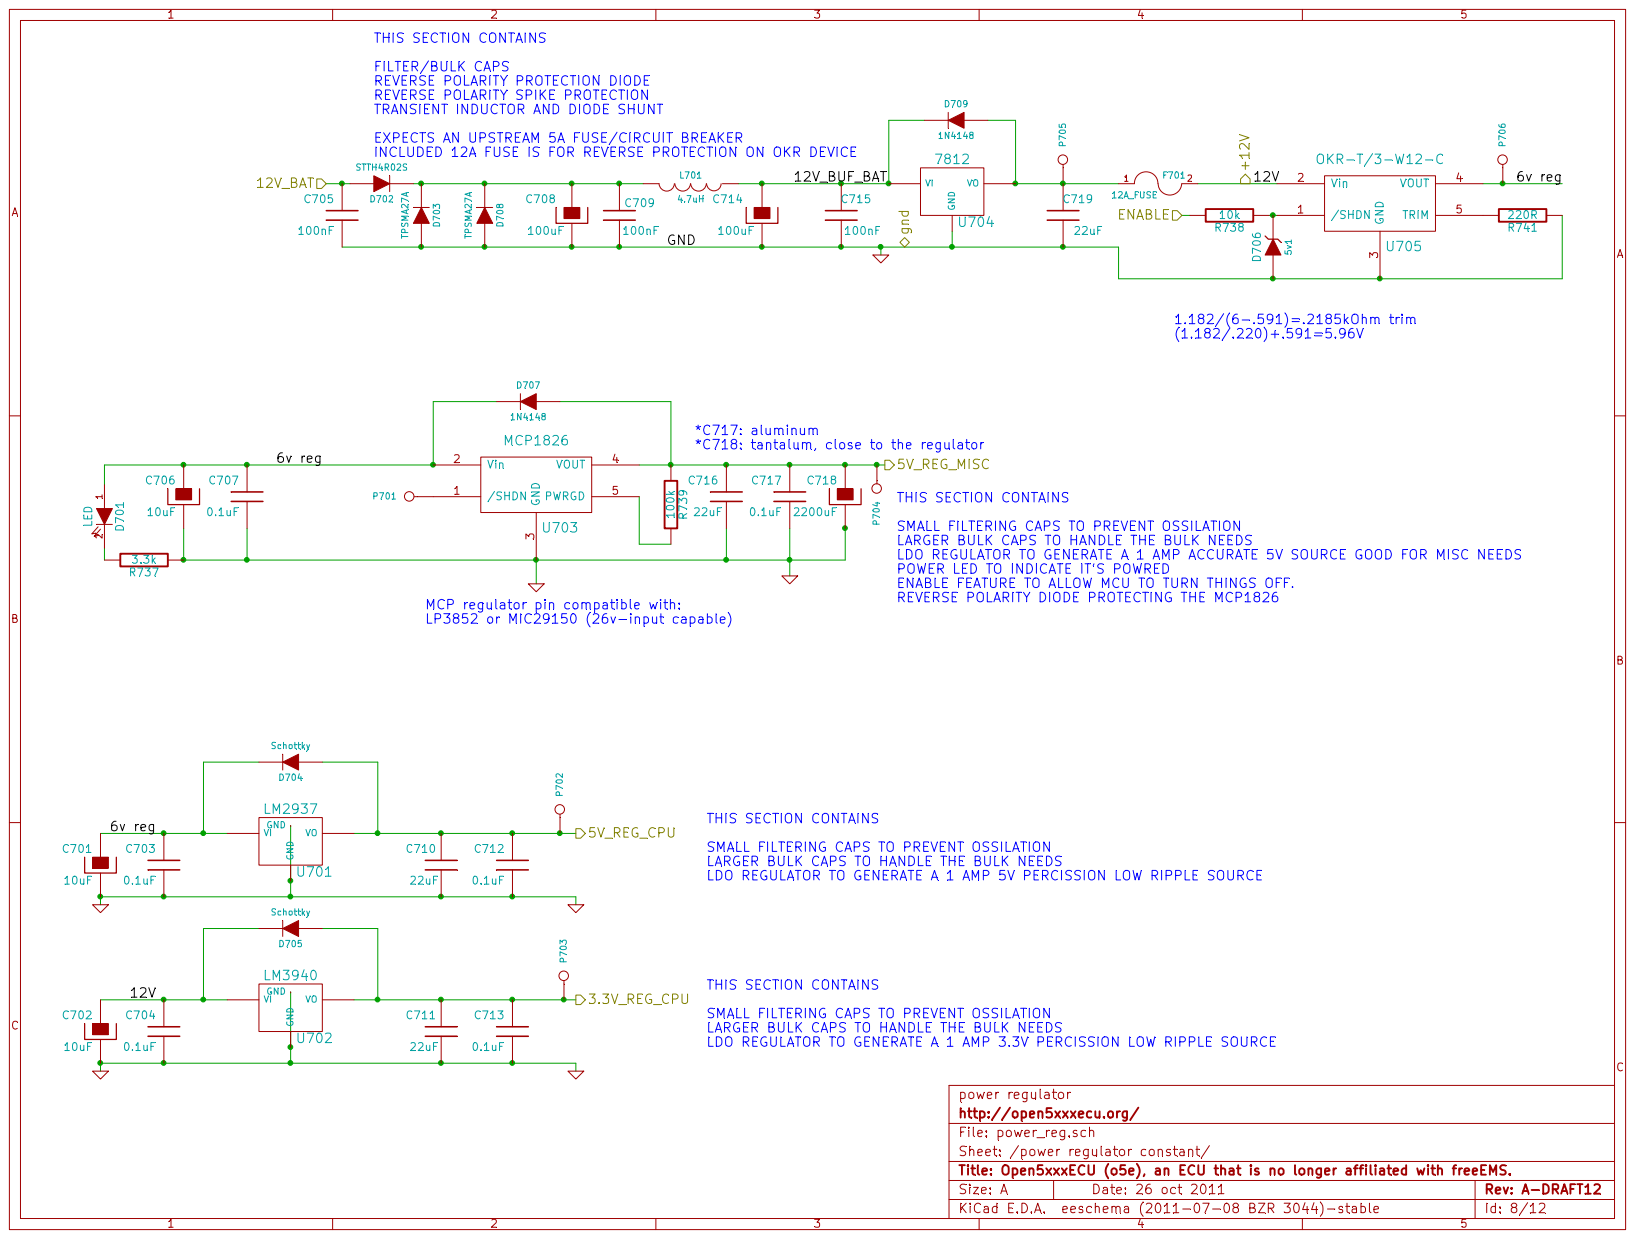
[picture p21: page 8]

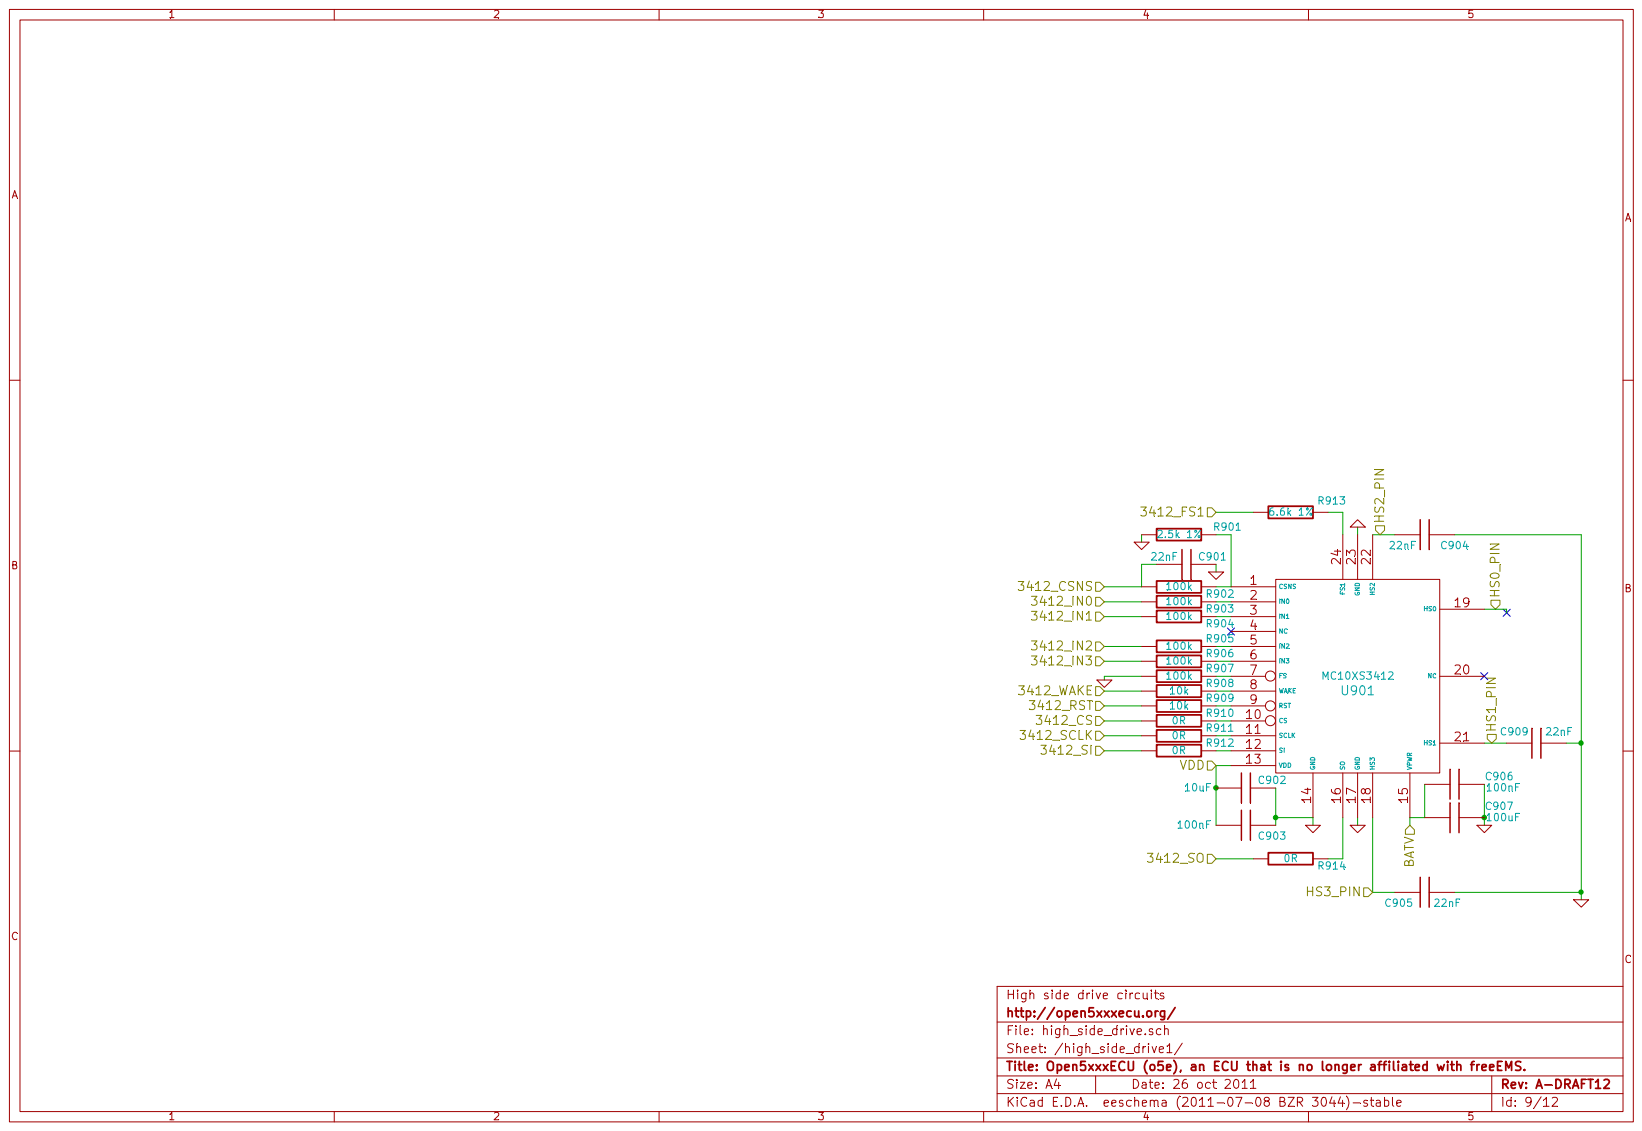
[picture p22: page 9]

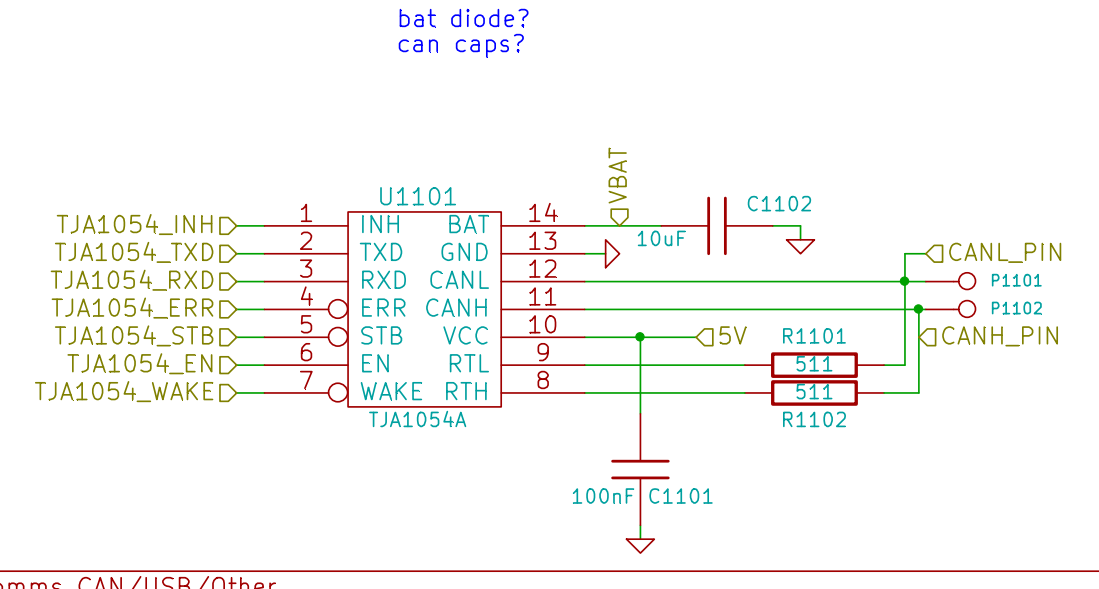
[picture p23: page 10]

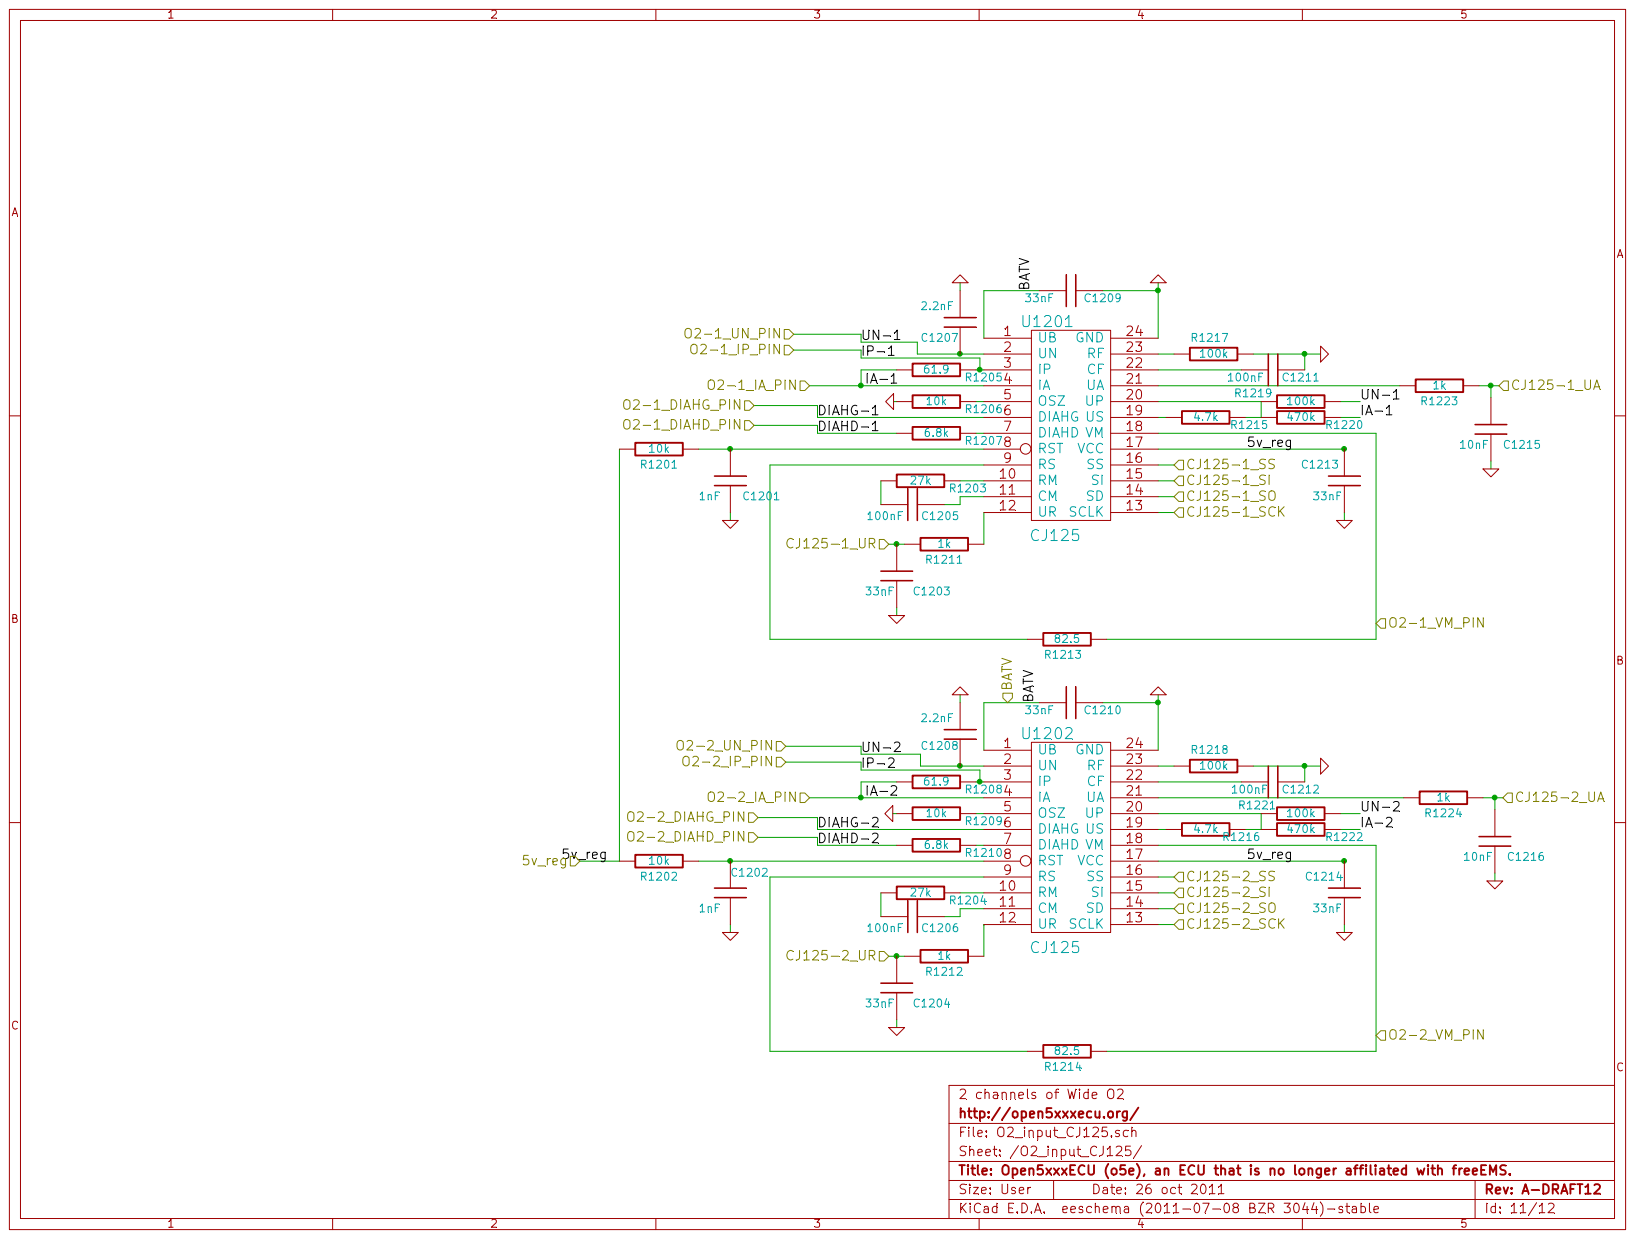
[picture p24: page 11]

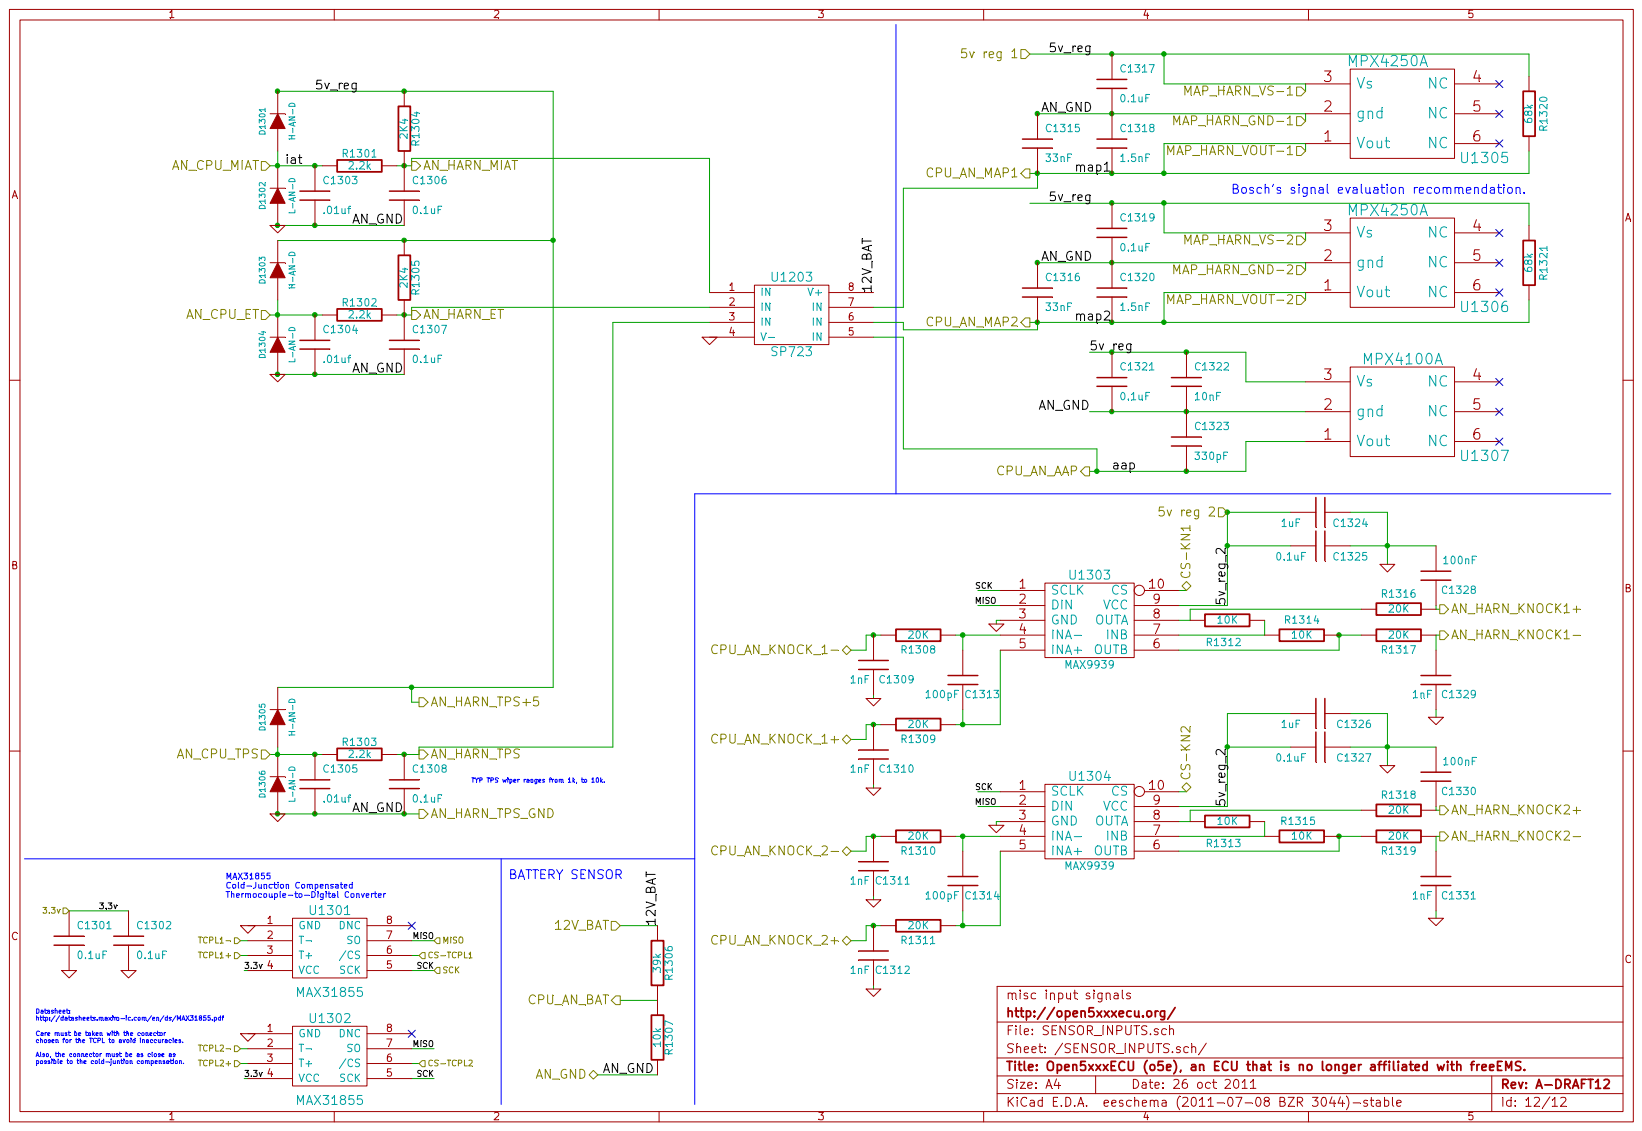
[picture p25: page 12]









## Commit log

2011-05-30 Created repo, includes work from Karri and myself, as well as 3D derived from files obtained from the MFG.
    [5810160005_rev_C.stp, cinch_start.brd]
2011-06-19 added power trace prediction spreadsheet
    [Trace Width Based on Power.xls]
2011-06-19 corrected my trace width prediction spread sheets. I attached the wrong one on my last commit.
    [Trace Width Based on Power.xls]
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2011-06-20 added .5 oz and 2 oz copper trace width specs to spread sheet.
    [PCB_trace-via_specs.xls]
2011-06-24 Corrected placement of the L and R spring clips, added pictures to show how those clips work.
    [cinch_start.brd]
2011-07-24 added rough modules for 112 molex harness and 5554 SOM Needs pins assignments, pads are done.
    [ModeICE_112Molex_PCB_outline.DXF, ModeICE_112Molex_PCB_outline_RB.DXF, pcb_outline.DWG]
2011-07-26 added schematic symbol for molex header, and 5554 SOM card
    [cinch_start.sch, molex_harness.sch, som_board.sch]
2011-07-31 mk_e corrected the pin outs of the modules and symbols. So we have 112 pin molex in a ModeICE enclosure at this point. I also changed the file structure around. I know the solid model reference locat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
    [$savepcb.brd, 4040011205_TYPE1.sldprt, 4040011206_TYPE2.sldprt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]
2011-08-01 updated some links, consolidated some files.
    Basically the board outline, and SOM are drafted at this point.
    [112 pin locaitons.xls, 4040011205_TYPE1.sldprt, 4040011206_TYPE2.sldprt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]
2011-08-01 oops, several small zip files were large when extracted. So I removed the large files.
    [527602009.SLDPRT, 527602009.stp, 53467-2009.SLDPRT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]
2011-08-01 Couple more fixes in KICAD linking/footprint filtering, also created .emp files as a backup
2011-08-02 compressed 3dstuff folder to save on file space.
    [112 pin locaitons.xls, 4040011205_TYPE1.sldprt, 4040011206_TYPE2.sldprt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]
2011-08-03 some restructuring, misc junk, checked in for archive purposes.
    [CAN_TJA1054.sch, CPU.sch, KNOCK_input.sch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]
2011-08-07 I did a fiar bit of work, and I want to be able to step back if I can, so this is a misc check in.
    [$savepcb.brd, CAN_TJA1054.sch, CPU.sch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]
2011-08-07 More work to capture, also I need it up there for collaboration purposes.
    [CAN_TJA1054.sch, CPU.sch, O2_input_CJ125.sch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]
2011-08-08 Started laying out the harness in DXF, initial schematic capture complete, except for harness.
    [CAN_TJA1054.sch, CPU.sch, Molex_112_pinout_r1.xls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]
2011-08-14 About to runs scripts to scrub the BOM's, so here's a backup copy in case it goes wrong.
    [$savepcb.brd, CAN_TJA1054.sch, CPU.sch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]
2011-08-14 caps have been done with the scripts next up is the resistors.
    [CAN_TJA1054.sch, CPU.sch, O2_input_CJ125.sch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]
2011-08-15 Looks like the bulk components are golden now, there are still a couple straglers, mostly switch mode power supply stuff.
    [CAN_TJA1054.sch, CPU.sch, O2_input_CJ125.sch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]
2011-08-19 harness connector is much more ironed out now. CPU is not connected.
    [CAN_TJA1054.sch, CPU.sch, Molex_112_pinout.xls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]
2011-08-20 several pins on the SOM are now connected.
    [CAN_TJA1054.sch, CPU.sch, O2_input_CJ125.sch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]
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2011-08-21 Errr, routing doesn't begin yet. Still need to iron our CPU sheet.
    [CAN_TJA1054.sch, CPU.sch, O2_input_CJ125.sch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]
2011-08-21 corrected con2 1-4 arrangement, updated SOM pin out, made draft attempt at ball park placement of critical components.
    [$savepcb.brd, CAN_TJA1054.sch, CPU.sch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]
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2011-09-02 Changed over voltage protected MOSFETs to SO8 footprints.
    [$savepcb.brd, CAN_TJA1054.sch, CPU.sch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]
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2011-09-05 Started putting down copper, got the power planes roughed in.
    [$savepcb.brd, CAN_TJA1054.sch, CPU.sch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]
2011-09-05 fixed P1,2,5,7 and PDF'ed.
    [CAN_TJA1054.sch, CPU.sch, O2_input_CJ125.sch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]
2011-09-12 Added simulations, and better predicted injector and ignition heat loads. Removed some 0R components to ease layout.
    [40V_OVP_MOSFET_heatload-over-RPM-range.xls, AD_notes.sch, CAN_TJA1054.sch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]
2011-09-13 added more simulation files, including diode snubber injector.
    [injector_notes_40V-OVP_HighZ_MOSFET.sch, injector_notes_snubbed_HighZ.sch, sym_osci.sch]
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2011-09-13 checking in with failed snubber cap circuit, also changed switch to have on resistance of .035 ohms instead of 0R
    [injector_notes.sch, injector_notes_40V-OVP_HighZ.sch, injector_notes_40V-OVP_LowZ.sch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]
2011-09-18 CAM1 and CRNK1 are drafted up. CAM2 and CRNK have been nicked.
    Added example brd file, for power fets on bottom side of board.
    [$savepcb.brd, 40V_OVP_MOSFET_heatload-over-RPM-range.xls, CAN_TJA1054.sch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]
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2011-09-24 added second knock, and second WO2 to PCB layout, modified 5V reg's for injection and ignition
    [$savepcb.brd, CAN_TJA1054.sch, CPU.sch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]
2011-09-25 first part of final routing for inj/ign 1-4
    [$savepcb.brd, CAN_TJA1054.sch, CPU.sch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]
2011-09-27 routed all inj/ign's such that they simply need to be connected to the MCU pins.
    [$savepcb.brd, CAN_TJA1054.sch, CPU.sch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]
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2011-09-30 Added some collected injector information, and QUCS calcs
    [injector_mH_averages.xls, injector_notes_40V-OVP_HighZ_23.0mH_15.9ohm.sch, injector_notes_40V-OVP_HighZ_32.8mH_15.9ohm.sch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]
2011-10-02 changed stepper from L297 to A4988 from pololu
    [$savepcb.brd, CAN_TJA1054.sch, CPU.sch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]
2011-10-07 Added some simulations for the AN protect lines
    [$savepcb.brd, 12V_short.sch, AN_protect_AC-sim.sch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]
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2011-10-14 Changed AN protections to match QUCS simulation predictions.
    [CAN_TJA1054.sch, CPU.sch, O2_input_CJ125.sch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]
2011-10-16 Made more progress on the AN protects and LS drive 33800
    [$savepcb.brd, CAN_TJA1054.sch, CPU.sch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]
2011-10-19 AN/DIGI's now point at processor, LS now points at processor, reg schematic drafted
    [$savepcb.brd, CAN_TJA1054.sch, CPU.sch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]
2011-10-20 changed some file names removing spaces, added gen2 notes, and some minor board layout changes.
    [$savepcb.brd, CAN_TJA1054.sch, CPU.sch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]
2011-10-21 about to position the regulators, save it as a backup copy
    [$savepcb.brd, CAN_TJA1054.sch, CPU.sch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]
2011-10-22 Regulators nearly done, everything is on the board. Starting to connect processor pins to circuits.
    [$savepcb.brd, CAN_TJA1054.sch, CPU.sch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]
2011-10-24 Ironed out Power and GND planes, worked on final pin out for processor to sub circuits.
    [$savepcb.brd, 2010_05_18_open_ecu_phycore_signals-ME_r10.xls, 2010_05_18_open_ecu_phycore_signals-ME_r14.xls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]
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
